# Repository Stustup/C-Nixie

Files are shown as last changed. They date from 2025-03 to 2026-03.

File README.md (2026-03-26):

<# CNIX - Nixie Tube Clock ->WORK IN PROGRESS

CNIX is a nixie tube clock which accepts many diffrent nixie tubes with only slight modifications to the tube carrier board. 

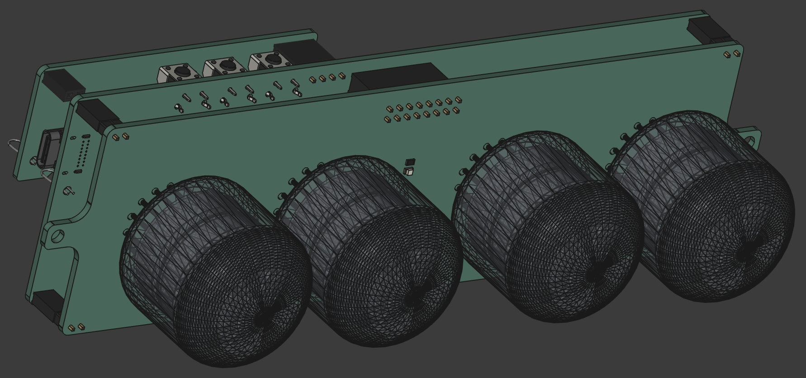
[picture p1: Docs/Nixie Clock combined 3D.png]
Nixie Clock tube board


The motivation was, that there are not many clocks out there that let you use almost any nixie tube you like. Most have fixed power supplies, 
underdesigned driver stages or inflexible microcontrollers. I hope to tackle these problems with an adjustable boost converter PSU, extremely 
flexible (and electrically protected) driver stages and an open source firmware written with free tools.

## Schematic

The control board consists of 3 parts:
- Power Supply
- Microcontroller
- I/O
- GPIO header for future ideas and feature expansion

Control board schematic

Power comes from a simple USB-C plug configured for 5V 3A max with the 5k1 CC line resistors. I thought about adding a PD controller for higher input voltages,
but this would just have added complexity and locked you into more expensive USB PD power supplies.

The µC is a STM32G051, because it has an included RTC *with* added Vbat pin for an external battery, so that the RTC remembers time even when powered off. 
The unused GPIOs are broken out to a connector, so that in the future one could add cool stuff like a radio time reciever, a display or wifi.
Time is set manually with the push buttons on top. 

The PSU is heavily inspired by [this site](https://surfncircuits.com/2018/02/03/optimizing-the-5v-to-170v-nixie-tube-power-supply-design-part-2/). I highly advise you giving it a read. The article goes in depth with boost converter design and its challanges.

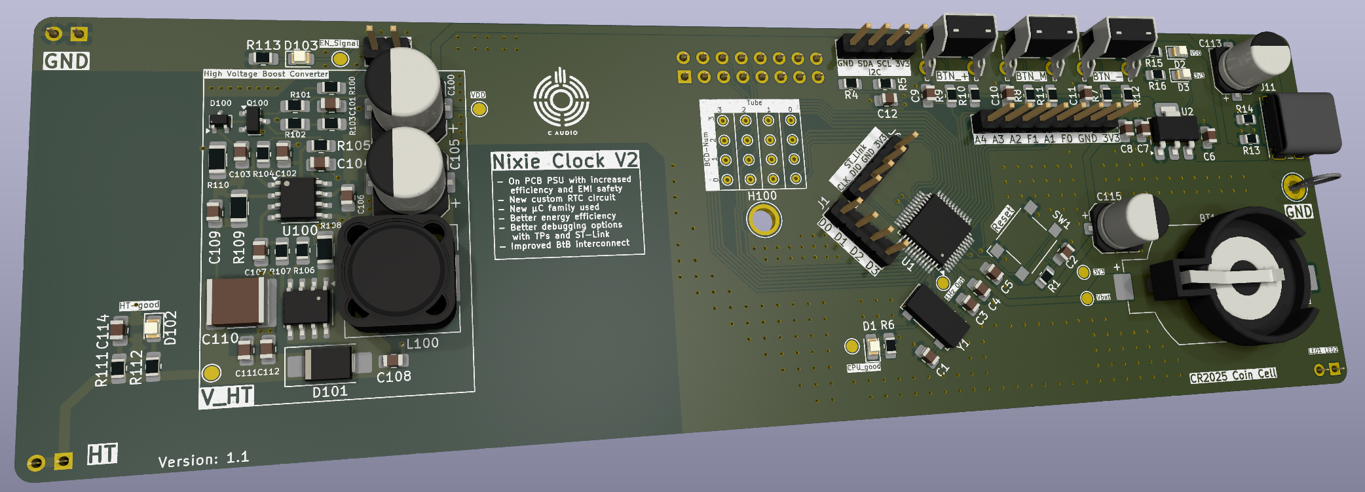
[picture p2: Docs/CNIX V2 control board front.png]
Control board 3d view


## Neat features

### Addon Boards
I designed an addon-board which just plugs into the broken out pins on the control board, to host all kinds of stuff. The one i already made has an DCF77 antenna for automatically getting the exact time OTA in germany. It also holds a HTU21 temperature and humidity sensor from TE, which can be accessed via a single press on the "menu" button on the control board. 
The addon-boards get detected via two pins (D2 a& D3), which form a 2 bit id system. so 0b11 means no board is connected, because i used internal pullups. the DCF77 board has the id 0b00, which deactivates the manual time setting menu and adds the temperature and humidity menu. 
With this all kinds of boards are possible, for example an ESP32 addon board with ESP-Home installed to integrate the clock and a sensor into homeassistant.

On the DCF77 Addon board there is a single pin to give structural strength to a simple perfboard on the main breakout bus. One can use this in tandem with the A1, A2, A3, A4, F0 and F1 pins.

![DCF77 Addon Board]

### Turn on/off timers
You can set power on and off times in the clock natively, so that the nixies dont always glow. With this the HT-power supply also gets deactivated to save power and lifespan of the parts. More advanced features like weekday dependant times have to be programmed directly into the µC, except if you want to code a big menu with just 3 buttons and 2 LEDs.

## TODO

- Change to new MCU. STM32H5 or ESP32. ESP32 for Wifi stuff like syncing time, Homeassistant integration etc. Could be done as module for the pinheader. STM32H5 for USBC pd
    - (DONE) Not necessary, BUT-> Create Plugin board for a DCF77 reciever conencting via GPIO
    - Addon board for Homeassistant Integration?
- (DONE) lower value caps for the LSE
- USB-PD (only with STM32H5) (Not neccessary)
- (DONE) HTU21 Temp and relative humidity sensor

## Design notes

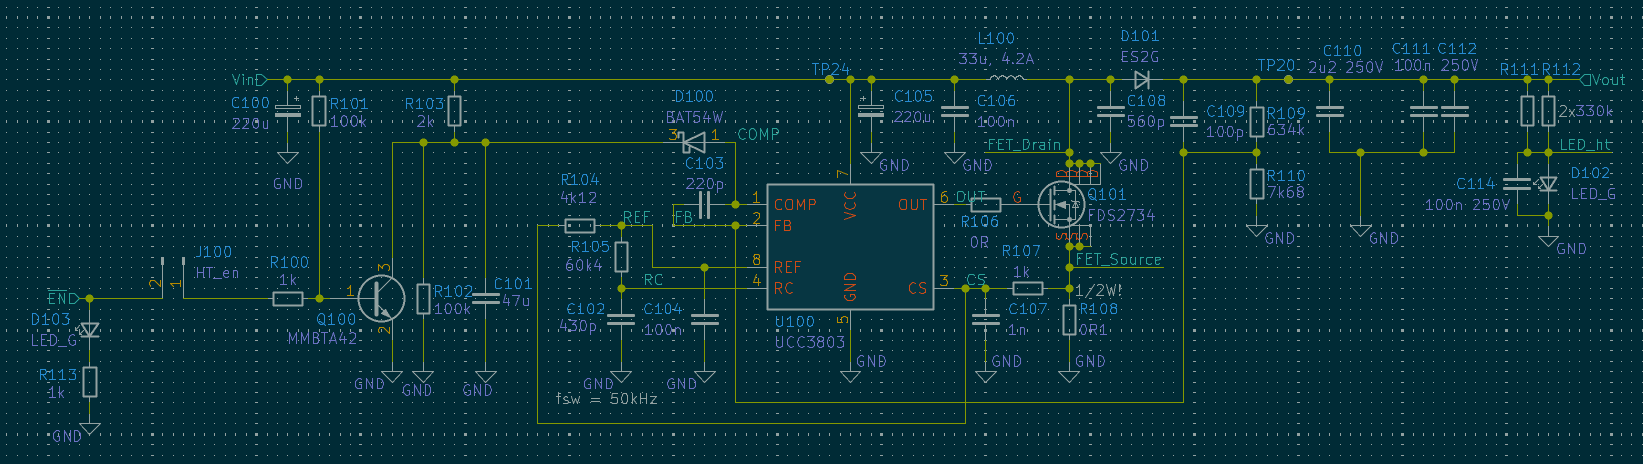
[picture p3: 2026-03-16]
Docs/CNIX V2 control board PSU schematic.png

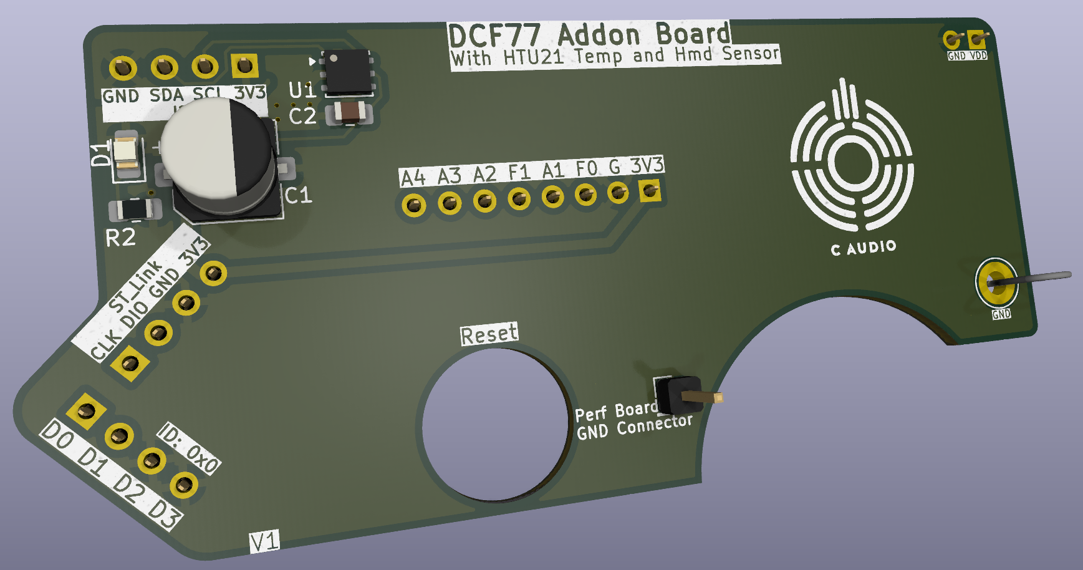
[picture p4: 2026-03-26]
Docs/CNIX V2 DCF77 Addon Board .png

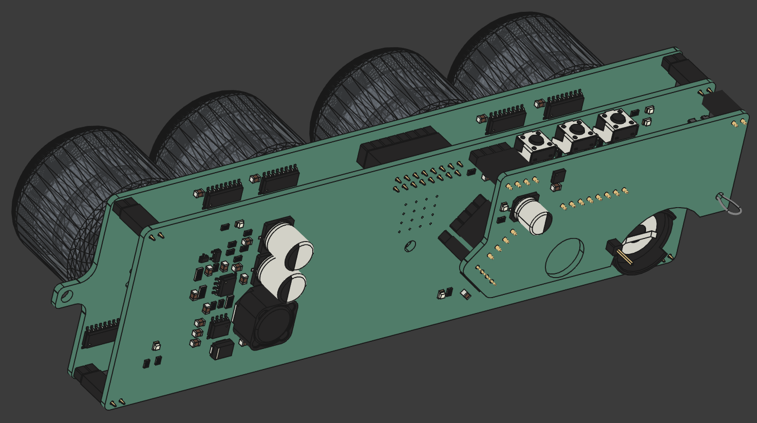
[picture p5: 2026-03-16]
Docs/CNIX V2 w Addon side.png

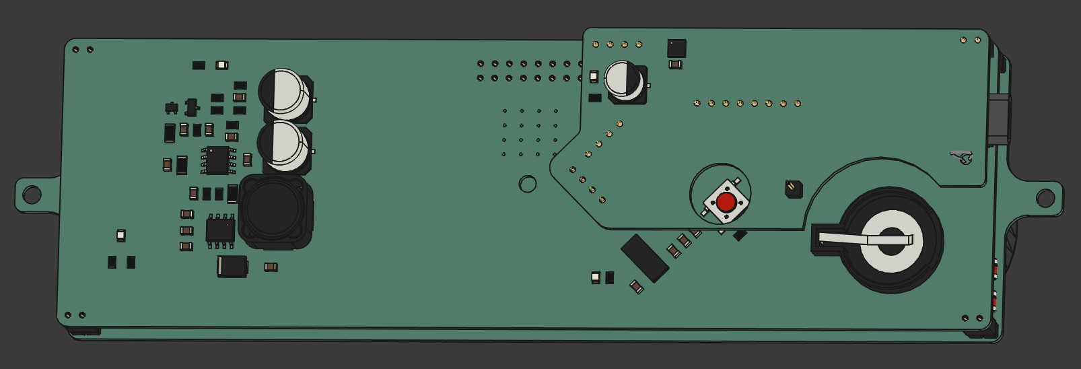
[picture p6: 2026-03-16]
Docs/CNIX V2 w addon back.png

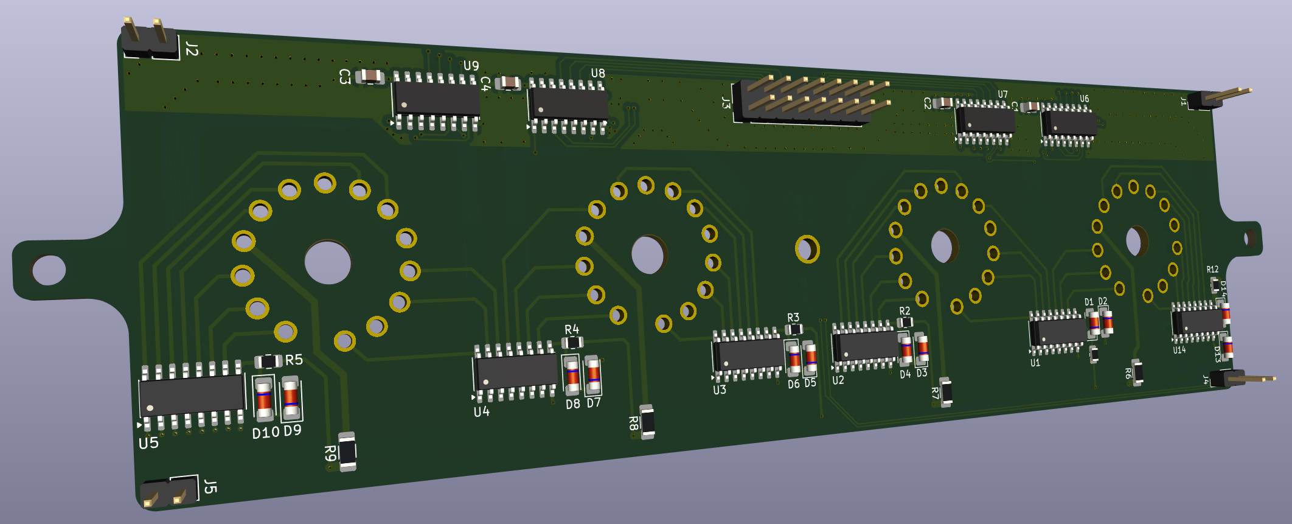
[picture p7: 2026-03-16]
Docs/CNIX V2 tube board side.png

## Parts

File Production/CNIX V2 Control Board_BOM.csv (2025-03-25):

Reference | Value | Qty | Mouser Nr. | Mouser URL | Datasheet | Footprint | DNP
BT1 | Coin Cell | 1 | 614-SMTU2032-LF.TR | https://www.mouser.de/ProductDetail/Renata/SMTU2032-LF.TR?qs=ZH26iPUykMX3HPCVulIAgQ%3D%3D | ~ | Battery:BatteryHolder_Renata_SMTU2032-LF_1x2032
C1,C3 | 18p | 2 | 80-C0805C180K5HACTU |  | ~ | Capacitor_SMD:C_0805_2012Metric_Pad1.18x1.45mm_HandSolder
C2,C4,C5,C8,C9,C10,C11,C104,C106 | 100n | 9 |  |  | ~ | Capacitor_SMD:C_0805_2012Metric_Pad1.18x1.45mm_HandSolder
C6,C12 | 10u | 2 | 187-CL21B106KPQNNNE |  | ~ | Capacitor_SMD:C_0805_2012Metric_Pad1.18x1.45mm_HandSolder
C7 | 22u | 1 | 187-CL21A226MQQNNNG |  | ~ | Capacitor_SMD:C_0805_2012Metric_Pad1.18x1.45mm_HandSolder
C100,C105 | 220u | 2 | 647-UUX1E221MNL6GS |  | ~ | Capacitor_SMD:CP_Elec_8x10
C101 | 47u | 1 | 187-CL21A476MRYNNNE |  | ~ | Capacitor_SMD:C_0805_2012Metric_Pad1.18x1.45mm_HandSolder
C102 | 430p | 1 | 80-C0805C431J5G |  | ~ | Capacitor_SMD:C_0805_2012Metric_Pad1.18x1.45mm_HandSolder
C103 | 220p | 1 | 710-885012207082 |  | ~ | Capacitor_SMD:C_0805_2012Metric_Pad1.18x1.45mm_HandSolder
C107 | 1n | 1 | 187-CL21B102KBANNNC |  | ~ | Capacitor_SMD:C_0805_2012Metric_Pad1.18x1.45mm_HandSolder
C108 | 560p | 1 | 80-C0805C561K2R |  | ~ | Capacitor_SMD:C_0805_2012Metric_Pad1.18x1.45mm_HandSolder
C109 | 100p | 1 | 581-08052C101K |  | ~ | Capacitor_SMD:C_0805_2012Metric_Pad1.18x1.45mm_HandSolder
C110,C111 | 1u 250V | 2 | 810-CGA4J3X7T2E104MA |  | ~ | Capacitor_SMD:C_0805_2012Metric_Pad1.18x1.45mm_HandSolder
C112 | 100n 250V | 1 | 810-CGA4J3X7T2E104MA |  | ~ | Capacitor_SMD:C_0805_2012Metric_Pad1.18x1.45mm_HandSolder
C113 | 100u 16V | 1 | 710-865080343009 | https://www.mouser.de/ProductDetail/Wurth-Elektronik/865080343009?qs=0KOYDY2FL28Gid9q%2FqirTQ%3D%3D | ~ | Capacitor_SMD:CP_Elec_6.3x7.7
D1,D2,D3 | LED_red | 3 |  |  | ~ | LED_SMD:LED_0805_2012Metric_Pad1.15x1.40mm_HandSolder
D100 | BAT54W | 1 | 637-BAT54W |  | https://assets.nexperia.com/documents/data-sheet/BAT54W_SER.pdf | Package_TO_SOT_SMD:SOT-323_SC-70
D101 | ES2G | 1 | 603-ES2G | https://eu.mouser.com/ProductDetail/YAGEO/ES2G?qs=2MMvu9PpTS2aUaVf2vcl5g%3D%3D | ~ | Diode_SMD:D_SMB_Handsoldering
D102,D103 | LED_G | 2 |  |  | ~ | LED_SMD:LED_0805_2012Metric
J1,J4 | EXT | 2 |  |  | ~ | Connector_PinHeader_2.54mm:PinHeader_1x04_P2.54mm_Vertical,Connector_PinHeader_2.54mm:PinHeader_1x08_P2.54mm_Vertical
J3 | Tube Out | 1 |  |  | ~ | Connector_PinSocket_2.54mm:PinSocket_2x08_P2.54mm_Vertical
J5 | I2C_ext | 1 |  |  | ~ | Connector_PinHeader_2.54mm:PinHeader_1x04_P2.54mm_Vertical
J6 | Prog | 1 |  |  | ~ | Connector_PinHeader_2.54mm:PinHeader_1x04_P2.54mm_Vertical
J7 | HT | 1 |  |  | ~ | Connector_PinSocket_2.54mm:PinSocket_1x02_P2.54mm_Vertical
J8,J9 | GND | 2 |  |  | ~ | Connector_PinSocket_2.54mm:PinSocket_1x02_P2.54mm_Vertical
J10 | LED | 1 |  |  | ~ | Connector_PinSocket_2.54mm:PinSocket_1x02_P2.54mm_Vertical
J11 | USB_C_Receptacle | 1 |  |  | https://www.usb.org/sites/default/files/documents/usb_type-c.zip | Connector_USB:USB_C_Receptacle_GCT_USB4085
L100 | 68u, 2.8A | 1 | 871-B82477R4683M100 | https://www.mouser.de/ProductDetail/EPCOS-TDK/B82477R4683M100?qs=oQHyZtUHWNVcdFSxmnJQSQ%3D%3D | ~ | Inductor_SMD:L_12x12mm_H8mm
Q100 | MMBTA42 | 1 |  |  | https://www.onsemi.com/pub/Collateral/MMBTA42LT1-D.PDF | Package_TO_SOT_SMD:SOT-23
Q101 | FDS2734 | 1 | 512-FDS2734 | https://eu.mouser.com/ProductDetail/onsemi-Fairchild/FDS2734?qs=OZ%252BC78tOsDbAOUY0TECDsw%3D%3D | https://ngspice.sourceforge.io/docs/ngspice-html-manual/manual.xhtml#cha_MOSFETs | Package_SO:SO-8_3.9x4.9mm_P1.27mm
R1 | 10k | 1 |  |  | ~ | Resistor_SMD:R_0805_2012Metric_Pad1.20x1.40mm_HandSolder
R4,R5,R6,R7,R8,R9,R10,R11,R12,R15 | 4k7 | 10 | 603-RC0805FR-074K7P |  | ~ | Resistor_SMD:R_0805_2012Metric_Pad1.20x1.40mm_HandSolder
R13,R14 | 5k1 | 2 | 652-CR0805FX-5101ELF |  | ~ | Resistor_SMD:R_0805_2012Metric_Pad1.20x1.40mm_HandSolder
R16,R103 | 2k | 2 | 603-RC0805FR-132KL |  | ~ | Resistor_SMD:R_0805_2012Metric_Pad1.20x1.40mm_HandSolder
R100,R107,R113 | 1k | 3 |  |  | ~ | Resistor_SMD:R_0805_2012Metric_Pad1.20x1.40mm_HandSolder
R101,R102 | 100k | 2 |  |  | ~ | Resistor_SMD:R_0805_2012Metric_Pad1.20x1.40mm_HandSolder
R104 | 4k12 | 1 | 603-RC0805FR-074K12L |  | ~ | Resistor_SMD:R_0805_2012Metric_Pad1.20x1.40mm_HandSolder
R105 | 47k | 1 | 603-RE0805FRE0747KL |  | ~ | Resistor_SMD:R_0805_2012Metric_Pad1.20x1.40mm_HandSolder
R106 | 0R | 1 |  |  | ~ | Resistor_SMD:R_0805_2012Metric_Pad1.20x1.40mm_HandSolder
R108 | 0R1 | 1 | 660-UR73VH2BTTDR100F | https://www.mouser.de/ProductDetail/KOA-Speer/UR73VH2BTTDR100F?qs=HoCaDK9Nz5dTWFlShnTmnw%3D%3D | https://www.koaspeer.com/pdfs/UR73V.pdf | Resistor_SMD:R_1206_3216Metric_Pad1.30x1.75mm_HandSolder
R109 | 634k | 1 | 71-CRCW0805634KFKEA |  | ~ | Resistor_SMD:R_1206_3216Metric_Pad1.30x1.75mm_HandSolder
R110 | 7k68 | 1 | 603-RC0805FR-077K68L |  | ~ | Resistor_SMD:R_1206_3216Metric_Pad1.30x1.75mm_HandSolder
R111,R112 | 330k | 2 | 603-AC0805FR-07330KL |  | ~ | Resistor_SMD:R_0805_2012Metric_Pad1.20x1.40mm_HandSolder
SW1 | RST | 1 |  |  | ~ | Button_Switch_SMD:SW_SPST_Omron_B3FS-100xP
SW2 | SW_Plus | 1 |  |  | ~ | Button_Switch_THT:SW_Tactile_SPST_Angled_PTS645Vx31-2LFS
SW3 | SW_Menu | 1 |  |  | ~ | Button_Switch_THT:SW_Tactile_SPST_Angled_PTS645Vx31-2LFS
SW4 | SW_Minus | 1 |  |  | ~ | Button_Switch_THT:SW_Tactile_SPST_Angled_PTS645Vx31-2LFS
TP1,TP2,TP3,TP4,TP5,TP6,TP7,TP8,TP9,TP10,TP11,TP12,TP13,TP14,TP15,TP16,TP17,TP18,TP19,TP20,TP22,TP23,TP24 | TestPoint_Small | 23 |  |  | ~ | TestPoint:TestPoint_Pad_D1.5mm,TestPoint:TestPoint_THTPad_D1.0mm_Drill0.5mm
U1 | STM32G051C8T3 | 1 | 511-STM32G051C8T3 | https://www.mouser.de/ProductDetail/STMicroelectronics/STM32G051C8T3?qs=T%252BzbugeAwjiuqacRoZ%252BJAg%3D%3D | https://www.mouser.de/datasheet/2/389/stm32g051c6-2449954.pdf | Package_QFP:LQFP-48_7x7mm_P0.5mm
U2 | AMS1117-3.3 | 1 |  |  | http://www.advanced-monolithic.com/pdf/ds1117.pdf | Package_TO_SOT_SMD:SOT-223-3_TabPin2
U100 | UCC3803 | 1 | 595-UCC3803DTR |  | http://www.ti.com/lit/ds/symlink/ucc3800.pdf | Package_SO:SOIC-8_3.9x4.9mm_P1.27mm
Y1 | ABS25-32.768KHZ | 1 | 815-ABS25-32.7-6-1-T | https://www.mouser.de/ProductDetail/ABRACON/ABS25-32.768KHZ-6-1-T?qs=3LVMET7lfiORXXovA%252BX5Lg%3D%3D | ~ | Crystal:Crystal_SMD_Abracon_ABS25-4Pin_8.0x3.8mm

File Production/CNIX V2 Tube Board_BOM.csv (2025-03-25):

Reference | Value | Qty | Mouser URL | Mouser Nr. | Datasheet | Footprint | DNP
C1,C2,C3,C4 | 100n | 4 |  |  | ~ | Capacitor_SMD:C_0805_2012Metric_Pad1.18x1.45mm_HandSolder
D1,D2,D3,D4,D5,D6,D7,D8,D9,D10,D13,D14 | TZMC47 | 12 | 78-TZMC47 |  | ~ | Diode_SMD:D_MiniMELF
D11,D12 | LED_Y | 2 |  |  | ~ | LED_SMD:LED_0805_2012Metric_Pad1.15x1.40mm_HandSolder
J1 | VDD | 1 |  |  | ~ | Connector_PinHeader_2.54mm:PinHeader_1x02_P2.54mm_Vertical
J2 | GND | 1 |  |  | ~ | Connector_PinHeader_2.54mm:PinHeader_1x02_P2.54mm_Vertical
J3 | Tube Conn | 1 |  |  | ~ | Connector_PinHeader_2.54mm:PinHeader_2x08_P2.54mm_Vertical
J4 | LED | 1 |  |  | ~ | Connector_PinHeader_2.54mm:PinHeader_1x02_P2.54mm_Vertical
J5 | HT | 1 |  |  | ~ | Connector_PinHeader_2.54mm:PinHeader_1x02_P2.54mm_Vertical
R1,R2,R3,R4,R5,R12 | 47k | 6 |  | 603-AC0805FR-1347KL | ~ | Resistor_SMD:R_0805_2012Metric
R6,R7,R8,R9 | 18k7 | 4 |  | 603-RC1206FR-0718K7L | ~ | Resistor_SMD:R_1206_3216Metric_Pad1.30x1.75mm_HandSolder
R10,R11 | 4k7 | 2 |  | 603-RC0805FR-074K7P | ~ | Resistor_SMD:R_0805_2012Metric_Pad1.20x1.40mm_HandSolder
U1,U2,U3,U4,U5,U14 | SN75468 | 6 | https://www.mouser.de/ProductDetail/Texas-Instruments/SN75468DR?qs=o4busQjUnQYJjs5DwORJyA%3D%3D | 595-SN75468DR | http://www.ti.com/lit/ds/slrs023e/slrs023e.pdf | Package_SO:SOIC-16_3.9x9.9mm_P1.27mm
U6,U7,U8,U9 | 4028 | 4 |  | 595-CD4028BM96 | http://www.intersil.com/content/dam/Intersil/documents/cd40/cd4028bms.pdf | Package_SO:SOIC-16_3.9x9.9mm_P1.27mm
U10 | IN-4_0 | 1 |  |  | https://www.tube-tester.com/sites/nixie/data/in-4/in-4-sh2.htm | .Nixie Tubes:IN-4
U11 | IN-4_1 | 1 |  |  | https://www.tube-tester.com/sites/nixie/data/in-4/in-4-sh2.htm | .Nixie Tubes:IN-4
U12 | IN-4_2 | 1 |  |  | https://www.tube-tester.com/sites/nixie/data/in-4/in-4-sh2.htm | .Nixie Tubes:IN-4
U13 | IN-4_3 | 1 |  |  | https://www.tube-tester.com/sites/nixie/data/in-4/in-4-sh2.htm | .Nixie Tubes:IN-4

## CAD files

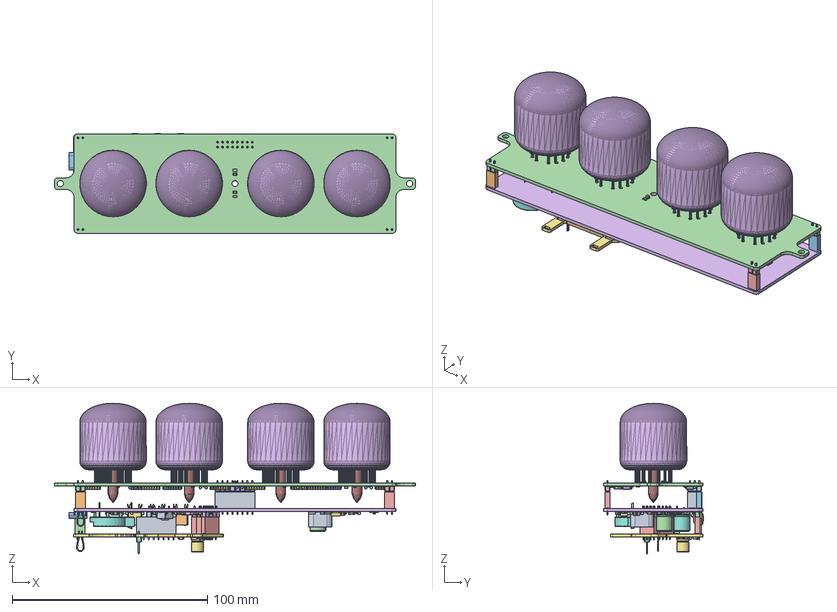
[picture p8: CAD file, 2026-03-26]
CAD/Nixie Clock 2 combined.FCStd
185.0 x 51.2 x 77.1 mm
R_1206_3216Metric
C_0805_2012Metric
C_0805_2012Metric002
C_0805_2012Metric004
C_0805_2012Metric006
R_0805_2012Metric
LED_0805_2012Metric
C_0805_2012Metric008
C_0805_2012Metric010
C_0805_2012Metric012
R_0805_2012Metric002
C_0805_2012Metric014
R_0805_2012Metric004
R_0805_2012Metric006
C_0805_2012Metric016
C_0805_2012Metric018
R_0805_2012Metric008
C_0805_2012Metric020
R_0805_2012Metric010
R_0805_2012Metric012
R_0805_2012Metric014
MicroCrystal_CC1V_T1A
R_0805_2012Metric016
R_1206_3216Metric002
C_0805_2012Metric022
R_0805_2012Metric018
R_0805_2012Metric020
C_0805_2012Metric024
R_0805_2012Metric022
TestPoint_Loop_D3.80mm_Drill2.0mm
SW_Tactile_SPST_Angled_PTS645Vx31-2LFS
SOT_23
PinHeader_1x06_P254mm_Vertical
C_0805_2012Metric026
R_0805_2012Metric024
C_0805_2012Metric028
C_0805_2012Metric030
R_0805_2012Metric026
C_0805_2012Metric032
SW_Tactile_SPST_Angled_PTS645Vx31-2LFS002
L_Coilcraft_MSS1278-XXX
R_0805_2012Metric028
SOT_323_SC_70
R_0805_2012Metric030
C_0805_2012Metric034
R_0805_2012Metric032
LED_0805_2012Metric002
CP_Elec_8x10
C_0805_2012Metric036
R_0805_2012Metric034
R_0805_2012Metric036
SOIC_8_39x49mm_P127mm
CQ assembly
CQ assembly001
CQ assembly002
CQ assembly003
CQ assembly004
CQ assembly005
CQ assembly006
CQ assembly007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

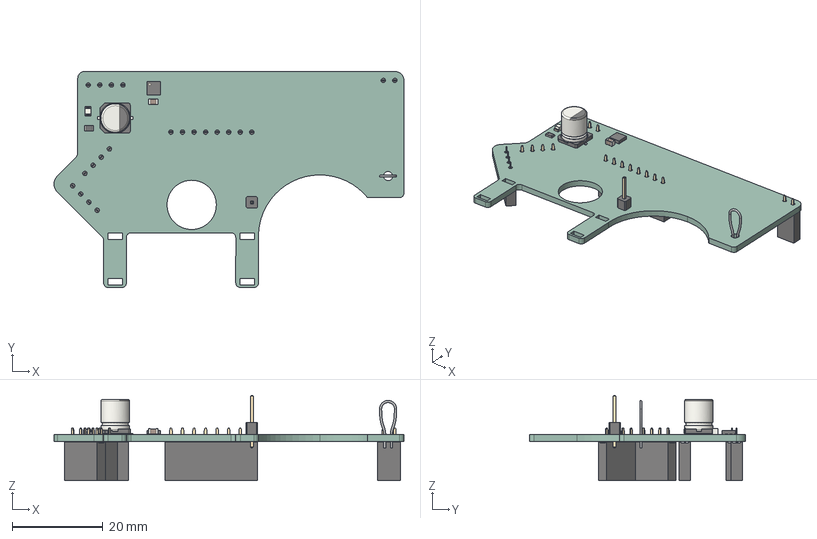
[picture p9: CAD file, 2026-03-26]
Hardware/Addon Boards/DCF77-Addon/3D/DCF77-Addon.step
77.0 x 47.5 x 18.7 mm
TestPoint_Loop_D3.80mm_Drill2.0mm
R_0805_2012Metric
CP_Elec_6.3x7.7
PinHeader_1x01_P2.54mm_Vertical
C_0805_2012Metric
LED_0805_2012Metric
DFN-6-1EP_3x3mm_P0.95mm_EP1.7x2.6mm
PinSocket_1x02_P2.54mm_Vertical
PinSocket_1x04_P2.54mm_Vertical x 3
PinSocket_1x08_P2.54mm_Vertical
DCF77-Addon_PCB

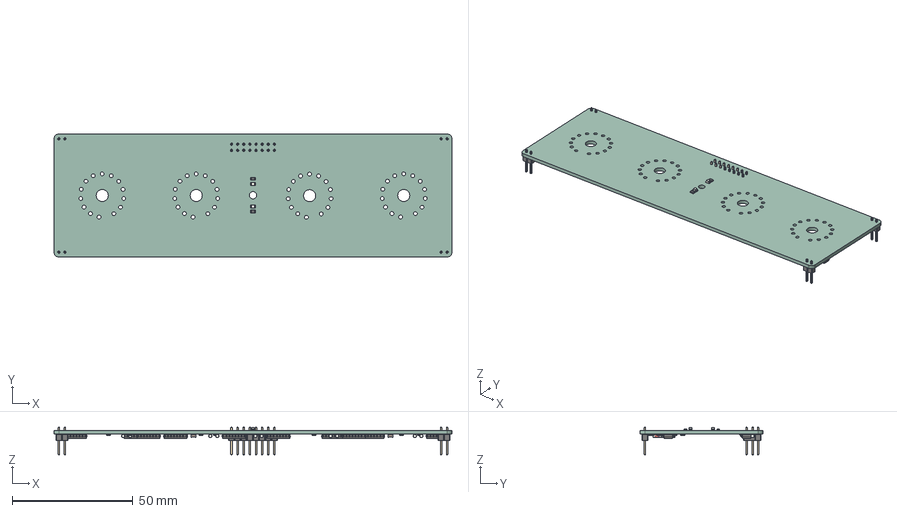
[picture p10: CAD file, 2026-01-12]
Hardware/Tube Board/CNIX V2 Tube Board IN13 (Placeholder)/CNIX V2 Tube Board.step
165.0 x 51.0 x 11.5 mm
R_0805_2012Metric x 8
LED_0805_2012Metric x 2
D_MiniMELF_Standard x 12
PinHeader_1x02_P254mm_Vertical x 4
SOIC_16_39x99mm_P127mm x 10
C_0805_2012Metric x 4
R_1206_3216Metric x 4
PinHeader_2x08_P254mm_Vertical
_autosave-Nixie Clock Tube Board V2_PCB

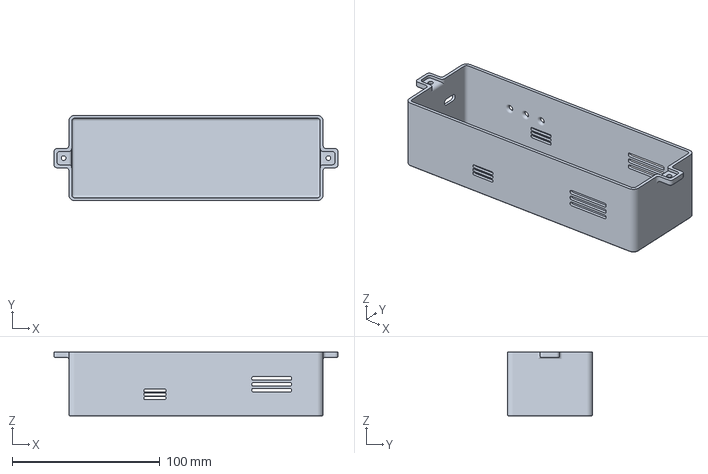
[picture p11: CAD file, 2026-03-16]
CAD/Nixie Clock 2 Case 3d-printing_3.3mf
192.0 x 57.8 x 43.2 mm

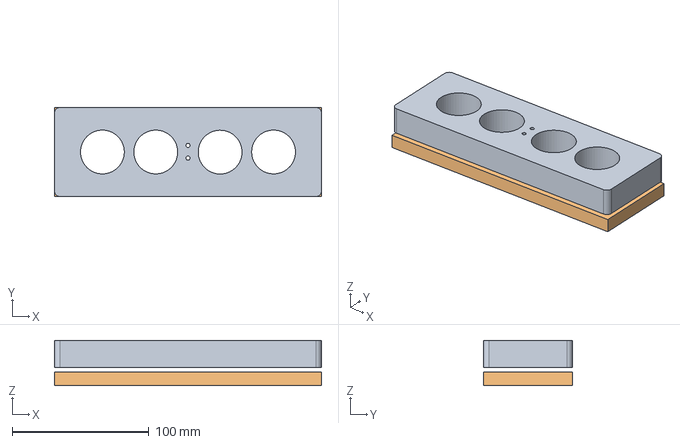
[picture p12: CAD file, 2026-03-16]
CAD/Nixie Clock 2 combined.sync-conflict-20260316-121056-62RYLVW.FCStd
195.0 x 65.0 x 33.2 mm
Frontplate
Fräs Vorlage Frontplatte

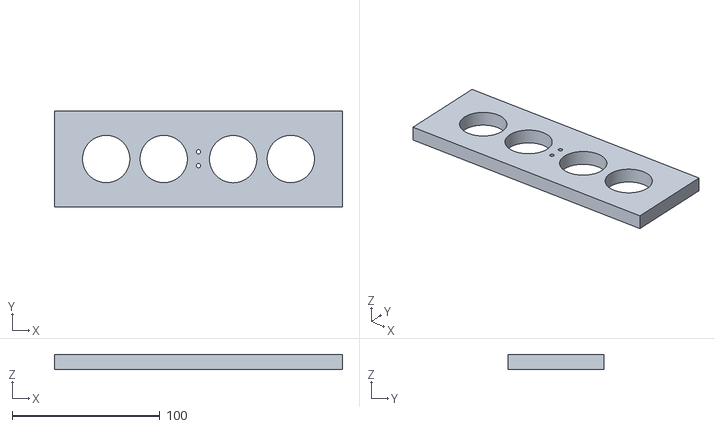
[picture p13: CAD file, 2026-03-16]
CAD/Nixie Clock 2 combined-Fräs Vorlage Frontplatte.stl
195.0 x 65.0 x 10.0

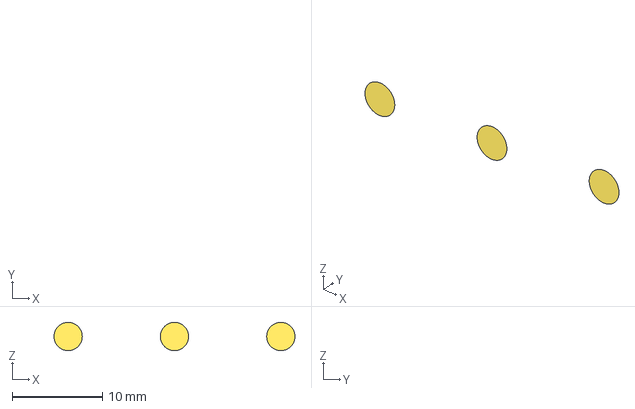
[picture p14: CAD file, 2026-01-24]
CAD/Nixie Clock 2 Case 3d-printing.step
26.7 x 0 x 3.14 mm

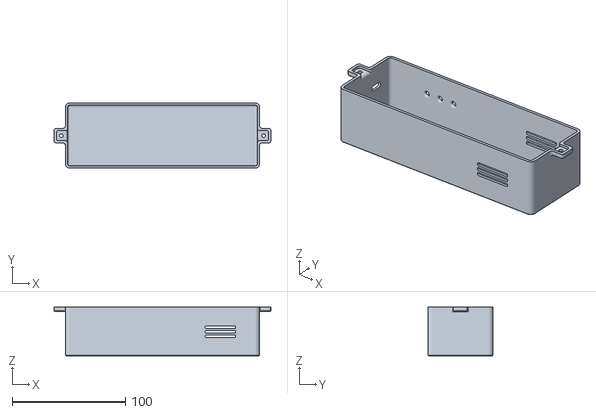
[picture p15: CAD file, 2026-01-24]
CAD/Nixie Clock 2 Case 3d-printing_2.stl
192.0 x 57.8 x 43.2

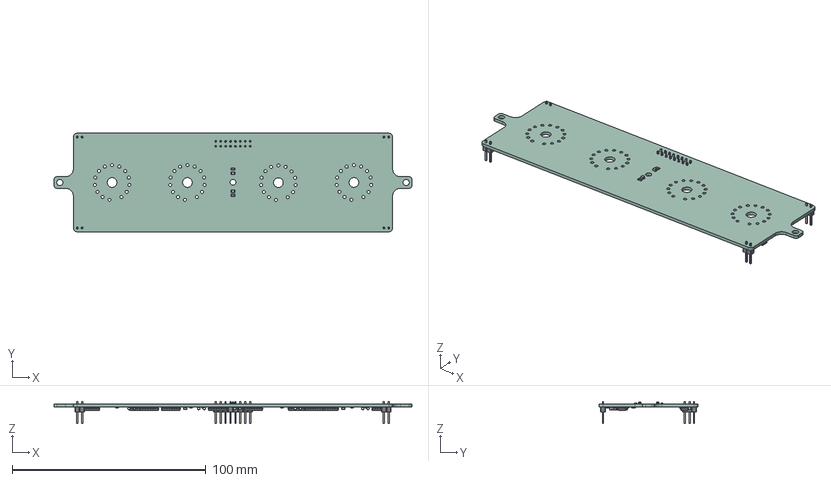
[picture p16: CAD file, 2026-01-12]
CAD/Nixie Clock Tube Board V2 IN4.step
185.0 x 51.0 x 11.5 mm
R_0805_2012Metric x 8
LED_0805_2012Metric x 2
D_MiniMELF x 12
PinHeader_1x02_P2.54mm_Vertical x 4
SOIC-16_3.9x9.9mm_P1.27mm x 10
C_0805_2012Metric x 4
R_1206_3216Metric x 4
PinHeader_2x08_P2.54mm_Vertical
CNIX V2 Tube Board_PCB

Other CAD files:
CAD/Case.FCStd
CAD/Nixie Clock 2 Case 3d-printing_3.stl
Hardware/Addon Boards/DCF77-Addon/3D/DCF77 Addon.FCStd

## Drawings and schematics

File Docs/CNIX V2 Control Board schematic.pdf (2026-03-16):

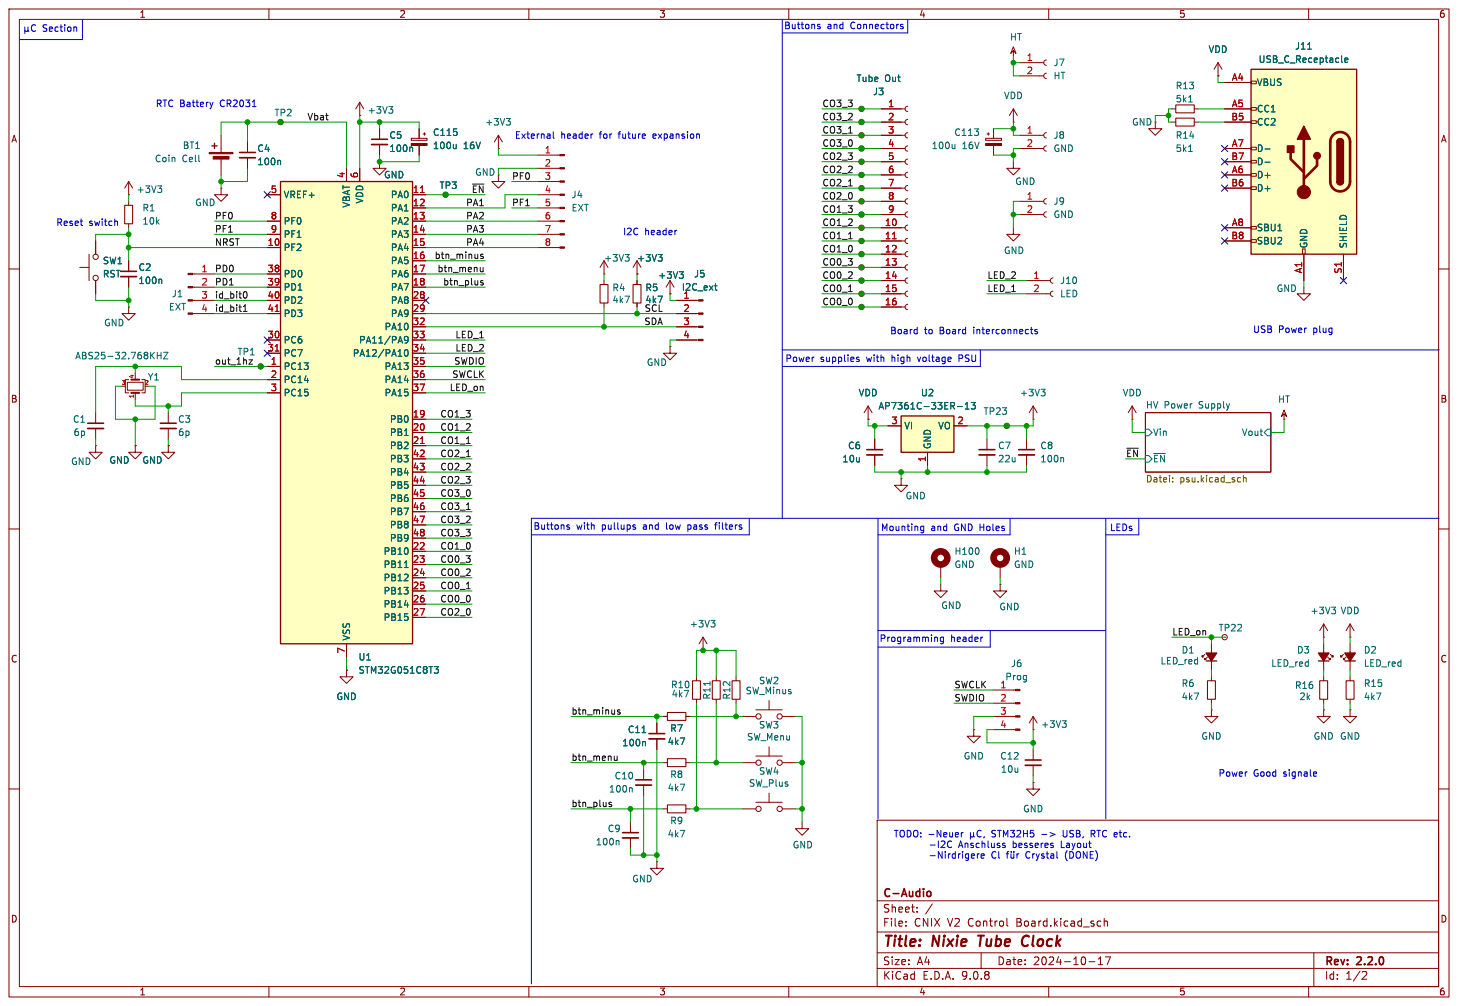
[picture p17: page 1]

Id: 1/2 Title: Nixie Tube Clock

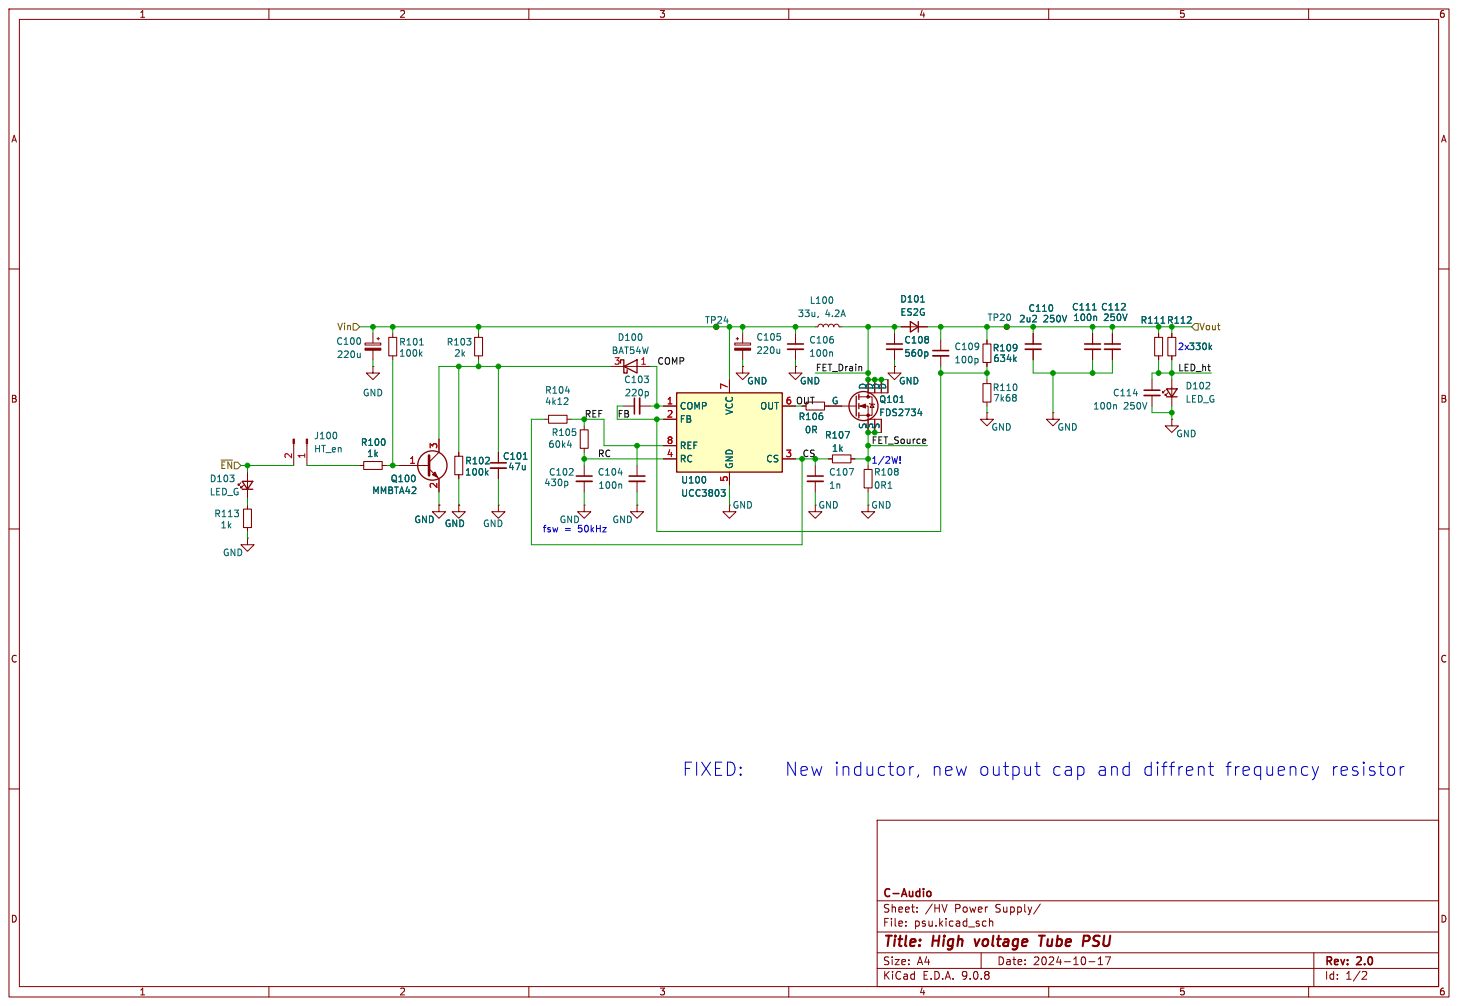
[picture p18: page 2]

Id: 1/2 Title: High voltage Tube PSU

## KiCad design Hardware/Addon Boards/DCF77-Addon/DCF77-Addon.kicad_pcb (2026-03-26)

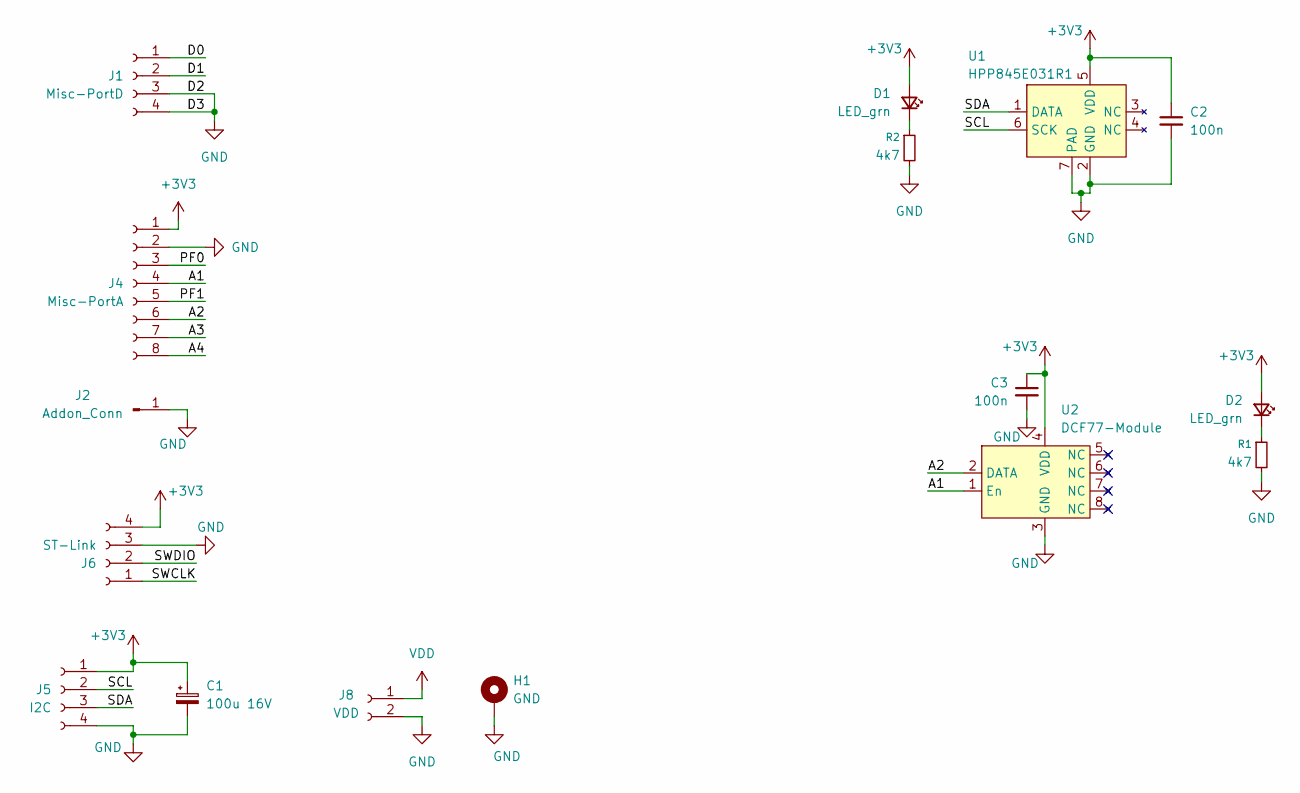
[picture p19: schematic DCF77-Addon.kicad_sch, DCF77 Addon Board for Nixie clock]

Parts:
C1: 100u 16V; CP_Elec_6.3x7.7
C2, C3: 100n; C_0805_2012Metric_Pad1.18x1.45mm_HandSolder
D1, D2: LED_grn; LED_0805_2012Metric_Pad1.15x1.40mm_HandSolder
H1: GND; TestPoint_Loop_D3.80mm_Drill2.0mm
J1: Misc-PortD; PinSocket_1x04_P2.54mm_Vertical
J2: Addon_Conn; PinHeader_1x01_P2.54mm_Vertical
J4: Misc-PortA; PinSocket_1x08_P2.54mm_Vertical
J5: I2C; PinSocket_1x04_P2.54mm_Vertical
J6: ST-Link; PinSocket_1x04_P2.54mm_Vertical
J8: VDD; PinSocket_1x02_P2.54mm_Vertical
R1, R2: 4k7; R_0805_2012Metric_Pad1.20x1.40mm_HandSolder
U1: HPP845E031R1; Maxim_TDFN-6-1EP_3x3mm_P0.95mm_EP1.5x2.3mm; Mouser Nr. 824-HPP845E031R1
U2: DCF77-Module

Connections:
+3V3: C1.1, C2.1, C3.1, D1.2 (A), D2.2 (A), J4.1, J5.1, J6.4, U1.5 (VDD), U2.4 (VDD)
/A1: J4.4, U2.1 (En)
/A2: J4.6, U2.2 (DATA)
/A3: J4.7
/A4: J4.8
/D0: J1.1
/D1: J1.2
/PF0: J4.3
/PF1: J4.5
/SCL: J5.2, U1.6 (SCK)
/SDA: J5.3, U1.1 (DATA)
/SWCLK: J6.1
/SWDIO: J6.2
GND: C1.2, C2.2, C3.2, H1.1, J1.3, J1.4, J2.1, J4.2, J5.4, J6.3, J8.2, R1.2, R2.2, U1.2 (GND), U1.7 (PAD), U2.3 (GND)
unnamed: D1.1 (K), R2.1
unnamed: D2.1 (K), R1.1
VDD: J8.1

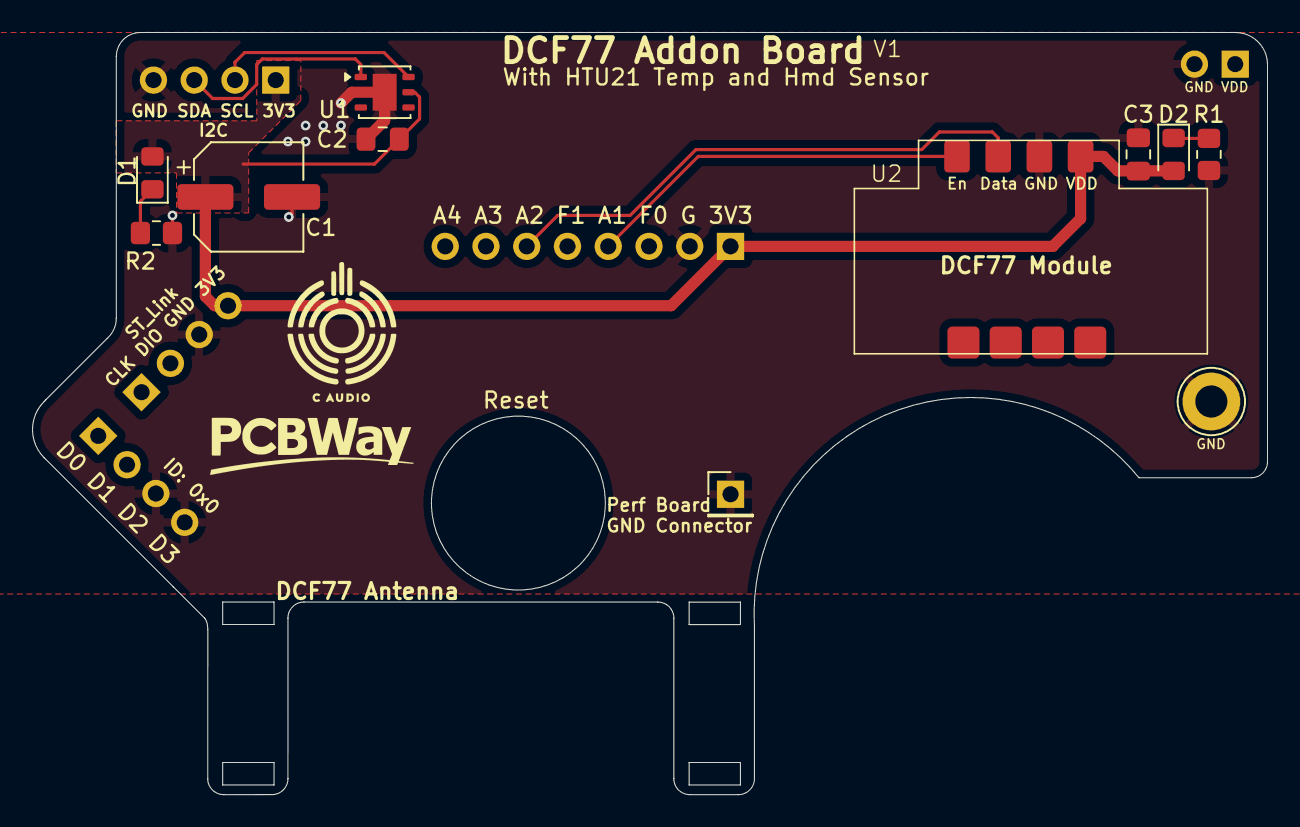
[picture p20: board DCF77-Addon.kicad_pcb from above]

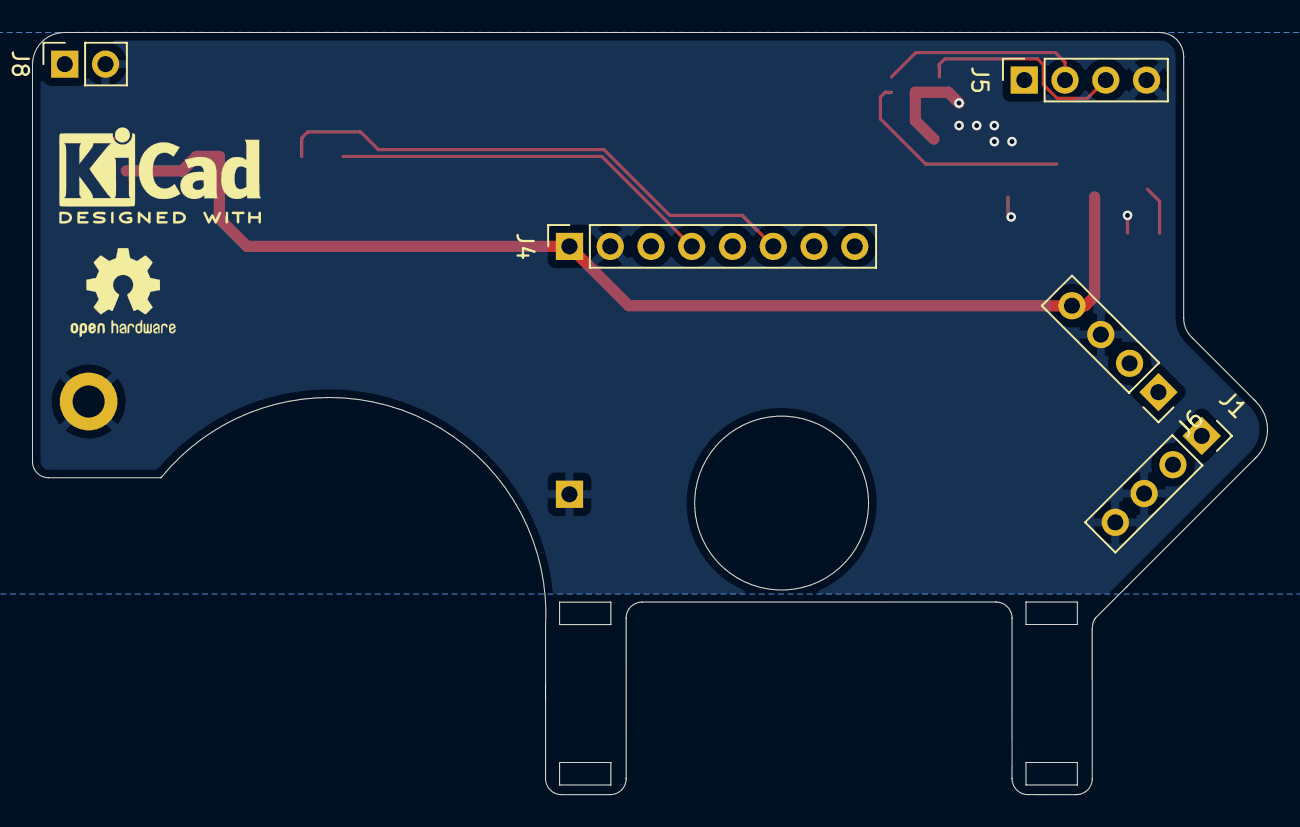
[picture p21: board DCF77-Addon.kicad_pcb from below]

Board: 2 copper layers, 77.0 x 47.5 mm, 16 parts (5 on the bottom side), 8 nets.

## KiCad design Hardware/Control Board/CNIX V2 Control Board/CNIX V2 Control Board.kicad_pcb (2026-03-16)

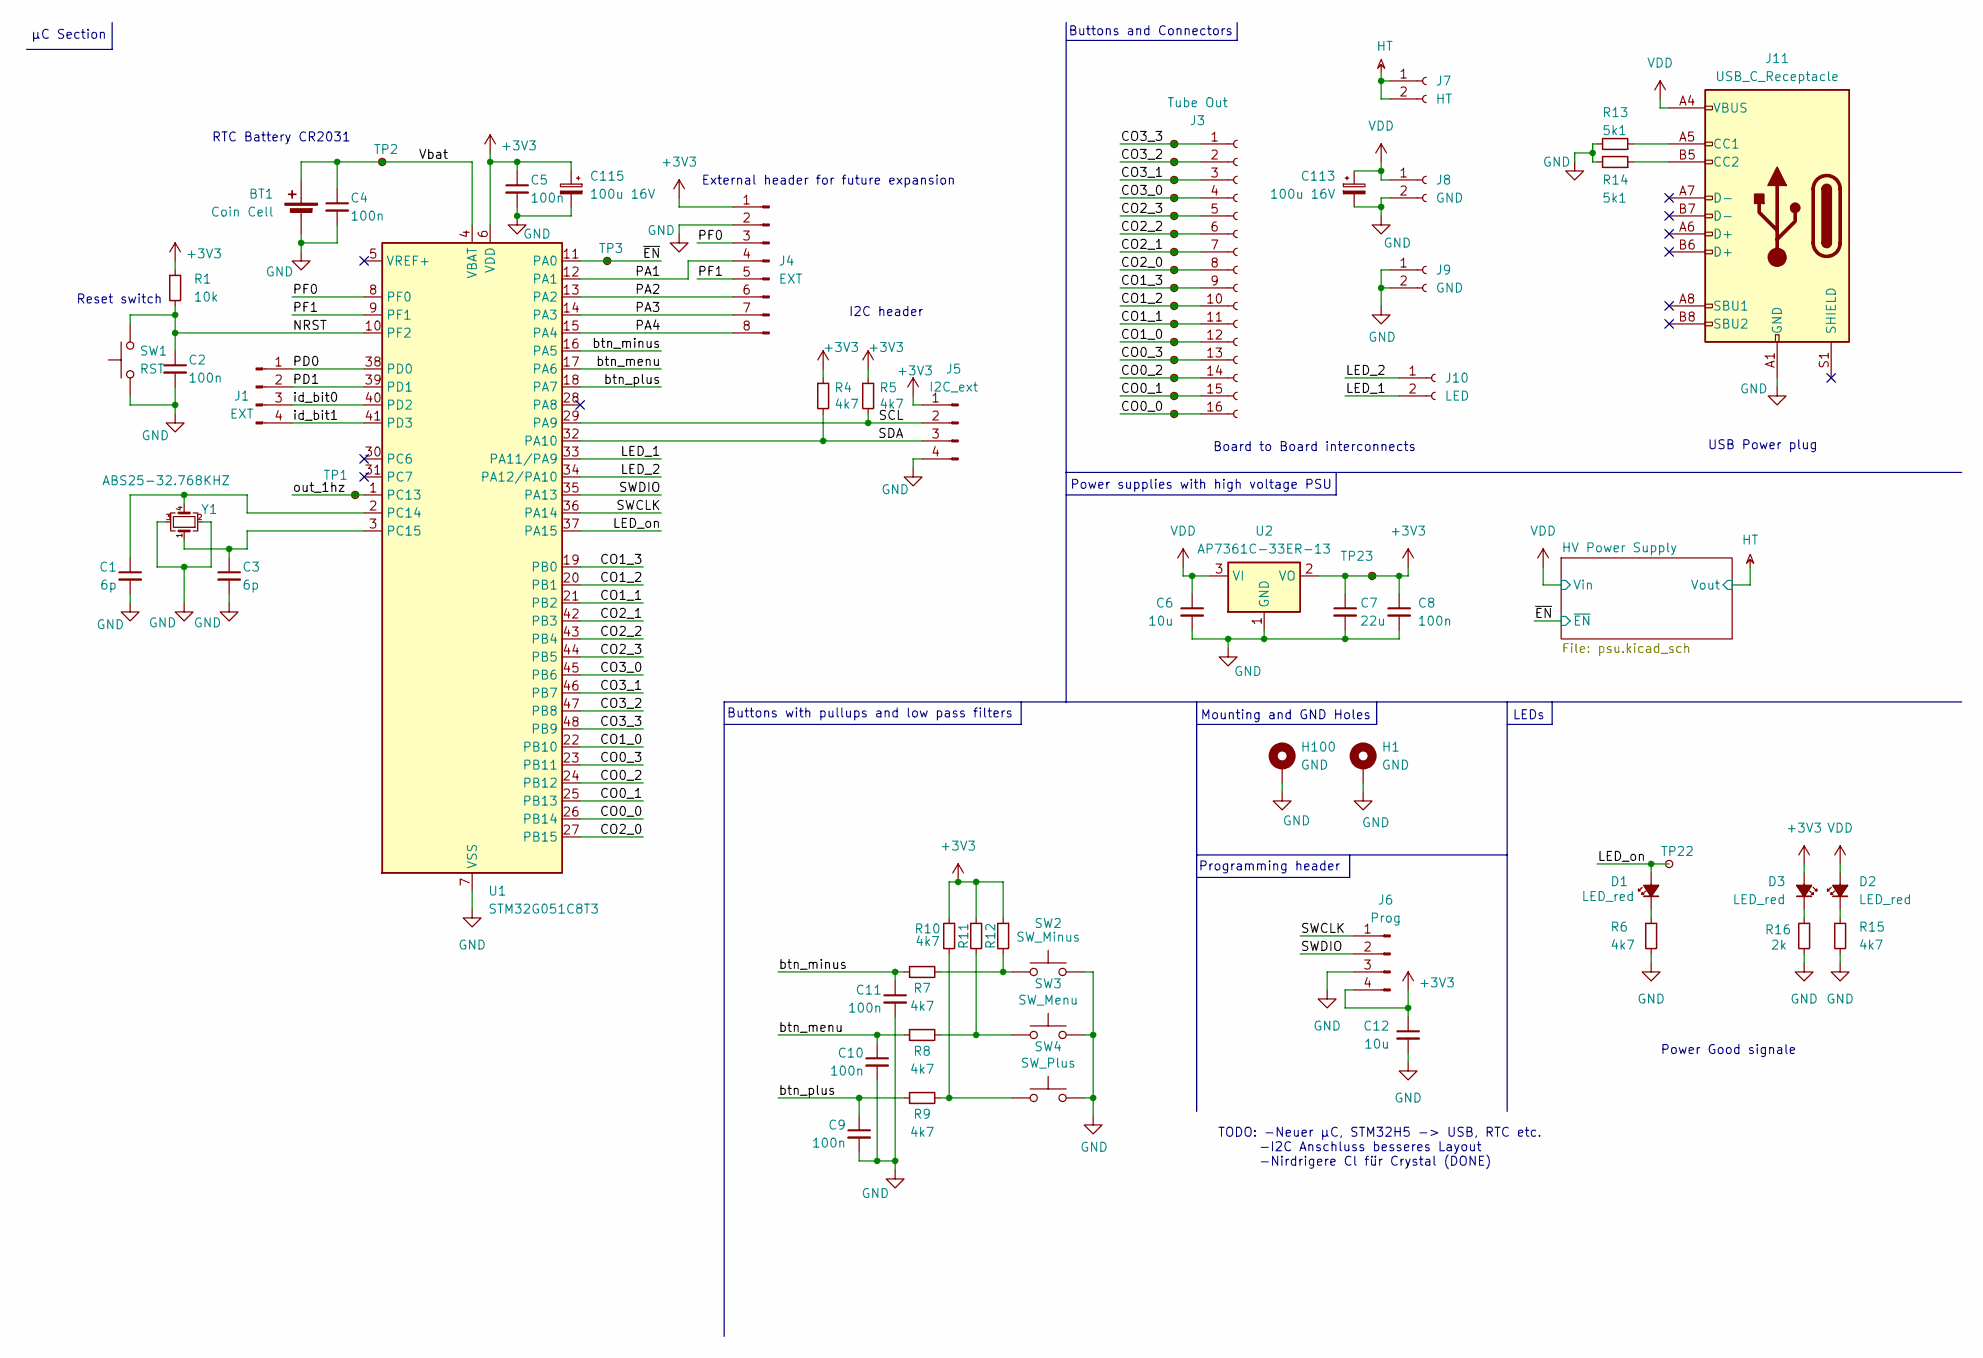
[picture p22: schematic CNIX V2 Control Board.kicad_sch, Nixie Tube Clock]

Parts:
BT1: Coin Cell; BatteryHolder_Renata_SMTU2032-LF_1x2032; Mouser Nr. 614-SMTU2032-LF.TR
C1, C3: 6p; C_0805_2012Metric_Pad1.18x1.45mm_HandSolder; Mouser Nr. 80-C0805C180K5HACTU
C2, C4, C5, C8, C9, C10, C11: 100n; C_0805_2012Metric_Pad1.18x1.45mm_HandSolder
C6, C12: 10u; C_0805_2012Metric_Pad1.18x1.45mm_HandSolder; Mouser Nr. 187-CL21B106KPQNNNE
C7: 22u; C_0805_2012Metric_Pad1.18x1.45mm_HandSolder; Mouser Nr. 187-CL21A226MQQNNNG
C113, C115: 100u 16V; CP_Elec_6.3x7.7; Mouser Nr. 710-865080343009
D1, D2, D3: LED_red; LED_0805_2012Metric_Pad1.15x1.40mm_HandSolder
H1: GND; TestPoint_Loop_D3.80mm_Drill2.0mm
H100: GND; TestPoint_Plated_Hole_D3.0mm
J1: EXT; PinHeader_1x04_P2.54mm_Vertical
J3: Tube Out; PinSocket_2x08_P2.54mm_Vertical
J4: EXT; PinHeader_1x08_P2.54mm_Vertical
J5: I2C_ext; PinHeader_1x04_P2.54mm_Vertical
J6: Prog; PinHeader_1x04_P2.54mm_Vertical
J7: HT; PinSocket_1x02_P2.54mm_Vertical
J8, J9: GND; PinSocket_1x02_P2.54mm_Vertical
J10: LED; PinSocket_1x02_P2.54mm_Vertical
J11: USB_C_Receptacle; USB_C_Receptacle_GCT_USB4085
R1: 10k; R_0805_2012Metric_Pad1.20x1.40mm_HandSolder
R4, R5, R6, R7, R8, R9, R10, R11, R12, R15: 4k7; R_0805_2012Metric_Pad1.20x1.40mm_HandSolder; Mouser Nr. 603-RC0805FR-074K7P
R13, R14: 5k1; R_0805_2012Metric_Pad1.20x1.40mm_HandSolder; Mouser Nr. 652-CR0805FX-5101ELF
R16: 2k; R_0805_2012Metric_Pad1.20x1.40mm_HandSolder; Mouser Nr. 603-RC0805FR-132KL
SW1: RST; SW_SPST_Omron_B3FS-100xP
SW2: SW_Minus; SW_Tactile_SPST_Angled_PTS645Vx31-2LFS
SW3: SW_Menu; SW_Tactile_SPST_Angled_PTS645Vx31-2LFS
SW4: SW_Plus; SW_Tactile_SPST_Angled_PTS645Vx31-2LFS
TP1, TP2, TP3, TP22, TP23: TestPoint_Small; TestPoint_Pad_D1.5mm
TP4, TP5, TP6, TP7, TP8, TP9, TP10, TP11, TP12, TP13, TP14, TP15, TP16, TP17, TP18, TP19: TestPoint_Small; TestPoint_THTPad_D1.0mm_Drill0.5mm
U1: STM32G051C8T3; LQFP-48_7x7mm_P0.5mm; Mouser Nr. 511-STM32G051C8T3
U2: AP7361C-33ER-13; SOT-223-3_TabPin2; Mouser-Nr. 621-AP7361C-33ER-13
Y1: ABS25-32.768KHZ; Crystal_SMD_Abracon_ABS25-4Pin_8.0x3.8mm; Mouser Nr. 815-ABS25-32.7-6-1-T

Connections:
+3V3: C5.1, C7.1, C8.1, C12.1, C115.1, D3.2 (A), J4.1, J5.1, J6.4, R1.1, R4.1, R5.1, R10.2, R11.1, R12.1, TP23.1, U1.6 (VDD), U2.2 (VO)
/CO0_0: J3.16, TP19.1, U1.26 (PB14)
/CO0_1: J3.15, TP18.1, U1.25 (PB13)
/CO0_2: J3.14, TP17.1, U1.24 (PB12)
/CO0_3: J3.13, TP16.1, U1.23 (PB11)
/CO1_0: J3.12, TP15.1, U1.22 (PB10)
/CO1_1: J3.11, TP14.1, U1.21 (PB2)
/CO1_2: J3.10, TP13.1, U1.20 (PB1)
/CO1_3: J3.9, TP12.1, U1.19 (PB0)
/CO2_0: J3.8, TP11.1, U1.27 (PB15)
/CO2_1: J3.7, TP10.1, U1.42 (PB3)
/CO2_2: J3.6, TP9.1, U1.43 (PB4)
/CO2_3: J3.5, TP8.1, U1.44 (PB5)
/CO3_0: J3.4, TP7.1, U1.45 (PB6)
/CO3_1: J3.3, TP6.1, U1.46 (PB7)
/CO3_2: J3.2, TP5.1, U1.47 (PB8)
/CO3_3: J3.1, TP4.1, U1.48 (PB9)
/LED_1: J10.2, U1.33 (PA11/PA9)
/LED_2: J10.1, U1.34 (PA12/PA10)
/LED_on: D1.2 (A), TP22.1, U1.37 (PA15)
/NRST: C2.1, R1.2, SW1.2, U1.10 (PF2)
/PA1: J4.4, U1.12 (PA1)
/PA2: J4.6, U1.13 (PA2)
/PA3: J4.7, U1.14 (PA3)
/PA4: J4.8, U1.15 (PA4)
/PD0: J1.1, U1.38 (PD0)
/PD1: J1.2, U1.39 (PD1)
/PF0: J4.3, U1.8 (PF0)
/PF1: J4.5, U1.9 (PF1)
/SCL: J5.2, R5.2, U1.29 (PA9)
/SDA: J5.3, R4.2, U1.32 (PA10)
/SWCLK: J6.1, U1.36 (PA14)
/SWDIO: J6.2, U1.35 (PA13)
/Vbat: BT1.1 (+), C4.1, TP2.1, U1.4 (VBAT)
/btn_menu: C10.1, R8.1, U1.17 (PA6)
/btn_minus: C11.1, R7.1, U1.16 (PA5)
/btn_plus: C9.1, R9.1, U1.18 (PA7)
/id_bit0: J1.3, U1.40 (PD2)
/id_bit1: J1.4, U1.41 (PD3)
/out_1hz: TP1.1, U1.1 (PC13)
/~EN: TP3.1, U1.11 (PA0); also elsewhere on the board
GND: BT1.2 (-), C1.2, C2.2, C3.2, C4.2, C5.2, C6.2, C7.2, C8.2, C9.2, C10.2, C11.2, C12.2, C113.2, C115.2, H1.1, H100.1, J4.2, J5.4, J6.3, J8.2, J9.1, J9.2, J11.A1 (GND), J11.A12 (GND), J11.B1 (GND), J11.B12 (GND), R6.2, R13.2, R14.2, R15.2, R16.2, SW1.1, SW2.2, SW3.2, SW4.2, U1.7 (VSS), U2.1 (GND), Y1.2, Y1.3; also elsewhere on the board
HT: J7.1, J7.2; also elsewhere on the board
unnamed: D1.1 (K), R6.1
unnamed: D2.1 (K), R15.1
unnamed: D3.1 (K), R16.1
unnamed: J11.A5 (CC1), R13.1
unnamed: J11.B5 (CC2), R14.1
unnamed: R9.2, R10.1, SW4.1
unnamed: R8.2, R11.2, SW3.1
unnamed: R7.2, R12.2, SW2.1
unnamed: C1.1, U1.2 (PC14), Y1.4
unnamed: C3.1, U1.3 (PC15), Y1.1
VDD: C6.1, C113.1, D2.2 (A), J8.1, J11.A4 (VBUS), J11.A9 (VBUS), J11.B4 (VBUS), J11.B9 (VBUS), U2.3 (VI); also elsewhere on the board

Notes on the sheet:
Board to Board interconnects
RTC Battery CR2031
µC Section
Programming header
External header for future expansion
Mounting and GND Holes
TODO: -Neuer µC, STM32H5 -> USB, RTC etc. -I2C Anschluss besseres Layout -Nirdrigere Cl für Crystal (DONE)
Power supplies with high voltage PSU
Buttons with pullups and low pass filters
Power Good signale
I2C header
USB Power plug
Reset switch
LEDs
Buttons and Connectors

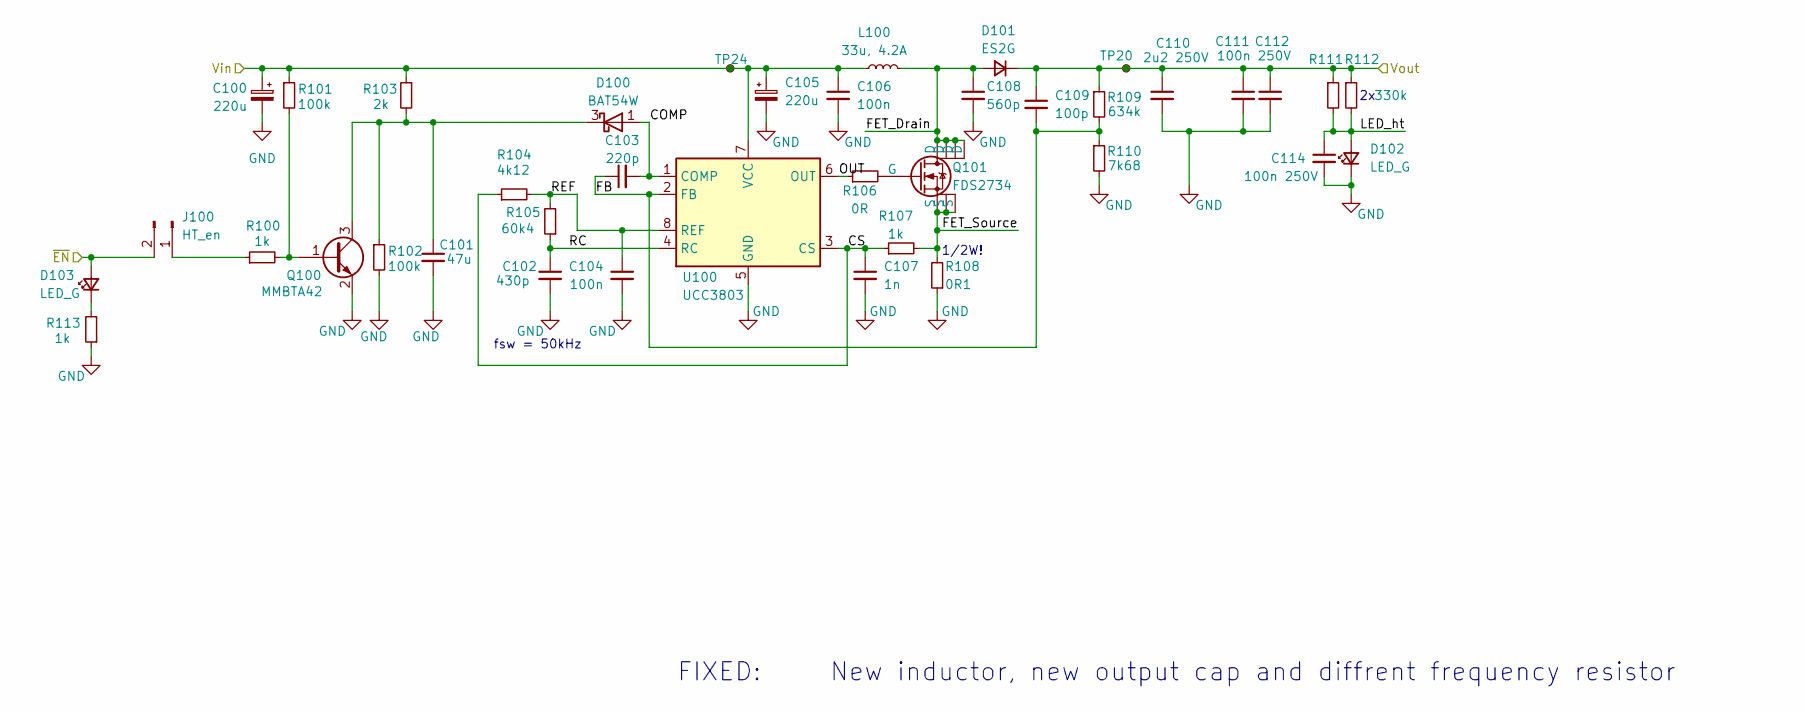
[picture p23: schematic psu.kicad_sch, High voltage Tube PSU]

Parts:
C100, C105: 220u; CP_Elec_8x10; Mouser Nr. 647-UUX1E221MNL6GS
C101: 47u; C_0805_2012Metric_Pad1.18x1.45mm_HandSolder; Mouser Nr. 187-CL21A476MRYNNNE
C102: 430p; C_0805_2012Metric_Pad1.18x1.45mm_HandSolder; Mouser Nr. 80-C0805C431J5G
C103: 220p; C_0805_2012Metric_Pad1.18x1.45mm_HandSolder; Mouser Nr. 710-885012207082
C104, C106: 100n; C_0805_2012Metric_Pad1.18x1.45mm_HandSolder
C107: 1n; C_0805_2012Metric_Pad1.18x1.45mm_HandSolder; Mouser Nr. 187-CL21B102KBANNNC
C108: 560p; C_0805_2012Metric_Pad1.18x1.45mm_HandSolder; Mouser Nr. 80-C0805C561K2R
C109: 100p; C_0805_2012Metric_Pad1.18x1.45mm_HandSolder; Mouser Nr. 581-08052C101K
C110: 2u2 250V; C_2220_5750Metric_Pad1.97x5.40mm_HandSolder; Mouser Nr. 710-885342214003
C111: 100nf 250V; C_0805_2012Metric_Pad1.18x1.45mm_HandSolder; Mouser Nr. 810-CGA4J3X7T2E104MA
C112, C114: 100n 250V; C_0805_2012Metric_Pad1.18x1.45mm_HandSolder; Mouser Nr. 810-CGA4J3X7T2E104MA
D100: BAT54W; SOT-323_SC-70; Mouser-Nr. 637-BAT54W
D101: ES2G; D_SMB_Handsoldering; Mouser Nr. 603-ES2G
D102, D103: LED_G; LED_0805_2012Metric
J100: HT_en; PinHeader_1x02_P2.54mm_Vertical
L100: 33u, 4.2A; L_12x12mm_H8mm; Mouser Nr. 7447709330
Q100: MMBTA42; SOT-23
Q101: FDS2734; SO-8_3.9x4.9mm_P1.27mm; Mouser Nr. 512-FDS2734
R100, R107, R113: 1k; R_0805_2012Metric_Pad1.20x1.40mm_HandSolder
R101, R102: 100k; R_0805_2012Metric_Pad1.20x1.40mm_HandSolder
R103: 2k; R_0805_2012Metric_Pad1.20x1.40mm_HandSolder; Mouser Nr. 603-RC0805FR-132KL
R104: 4k12; R_0805_2012Metric_Pad1.20x1.40mm_HandSolder; Mouser Nr. 603-RC0805FR-074K12L
R105: 60k4; R_0805_2012Metric_Pad1.20x1.40mm_HandSolder; Mouser Nr. 603-RE0805FRE0747KL
R106: 0R; R_0805_2012Metric_Pad1.20x1.40mm_HandSolder
R108: 0R1; R_1206_3216Metric_Pad1.30x1.75mm_HandSolder; Mouser Nr. 660-UR73VH2BTTDR100F
R109: 634k; R_1206_3216Metric_Pad1.30x1.75mm_HandSolder; Mouser Nr. 71-CRCW0805634KFKEA
R110: 7k68; R_1206_3216Metric_Pad1.30x1.75mm_HandSolder; Mouser Nr. 603-RC0805FR-077K68L
R111, R112: 330k; R_0805_2012Metric_Pad1.20x1.40mm_HandSolder; Mouser Nr. 603-AC0805FR-07330KL
TP20, TP24: TestPoint_Small; TestPoint_Pad_D1.5mm
U100: UCC3803; SOIC-8_3.9x4.9mm_P1.27mm; Mouser Nr. 595-UCC3803DTR

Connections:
/HV Power Supply/COMP: C103.2, D100.1 (A), U100.1 (COMP)
/HV Power Supply/CS: C107.1, R104.1, R107.1, U100.3 (CS)
/HV Power Supply/FB: C103.1, C109.2, R109.2, R110.1, U100.2 (FB)
/HV Power Supply/FET_Drain: C108.1, D101.2 (A), L100.2, Q101.5 (D), Q101.6 (D), Q101.7 (D), Q101.8 (D)
/HV Power Supply/FET_Source: Q101.1 (S), Q101.2 (S), Q101.3 (S), R107.2, R108.2
/HV Power Supply/LED_ht: C114.1, D102.2 (A), R111.2, R112.2
/HV Power Supply/OUT: R106.1, U100.6 (OUT)
/HV Power Supply/RC: C102.1, R105.1, U100.4 (RC)
/HV Power Supply/REF: C104.1, R104.2, R105.2, U100.8 (REF)
/~EN: D103.2 (A), J100.2; also elsewhere on the board
GND: C100.2, C101.2, C102.2, C104.2, C105.2, C106.2, C107.2, C108.2, C110.2, C111.2, C112.2, C114.2, D102.1 (K), Q100.2 (E), R102.2, R108.1, R110.2, R113.1, U100.5 (GND); also elsewhere on the board
HT: C109.1, C110.1, C111.1, C112.1, D101.1 (K), R109.1, R111.1, R112.1, TP20.1; also elsewhere on the board
unnamed: C101.1, D100.3 (K), Q100.3 (C), R102.1, R103.2
unnamed: D103.1 (K), R113.2
unnamed: J100.1, R100.1
unnamed: Q100.1 (B), R100.2, R101.2
unnamed: Q101.4 (G), R106.2
VDD: C100.1, C105.1, C106.1, L100.1, R101.1, R103.1, TP24.1, U100.7 (VCC); also elsewhere on the board

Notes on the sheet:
FIXED: New inductor, new output cap and diffrent frequency resistor
fsw = 50kHz
1/2W!

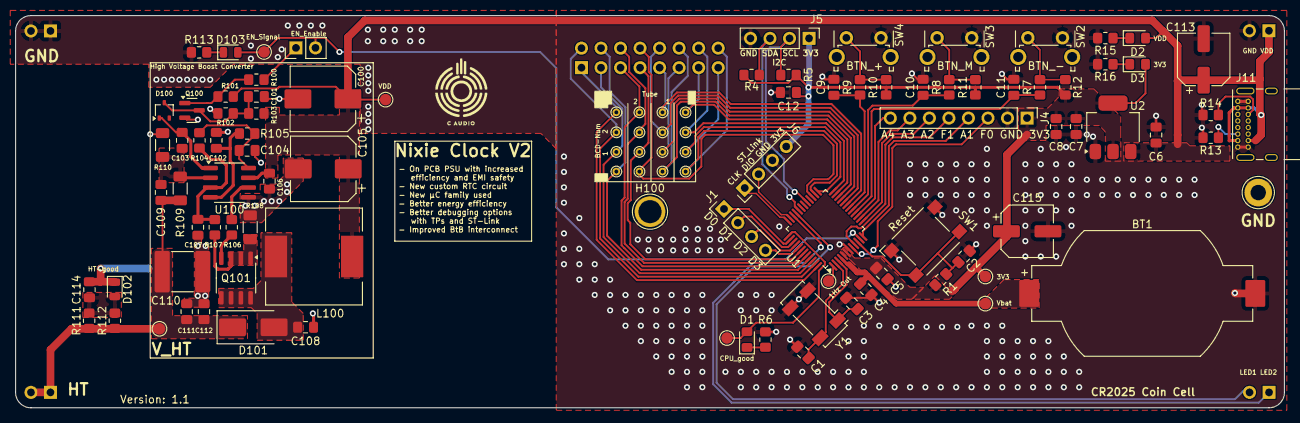
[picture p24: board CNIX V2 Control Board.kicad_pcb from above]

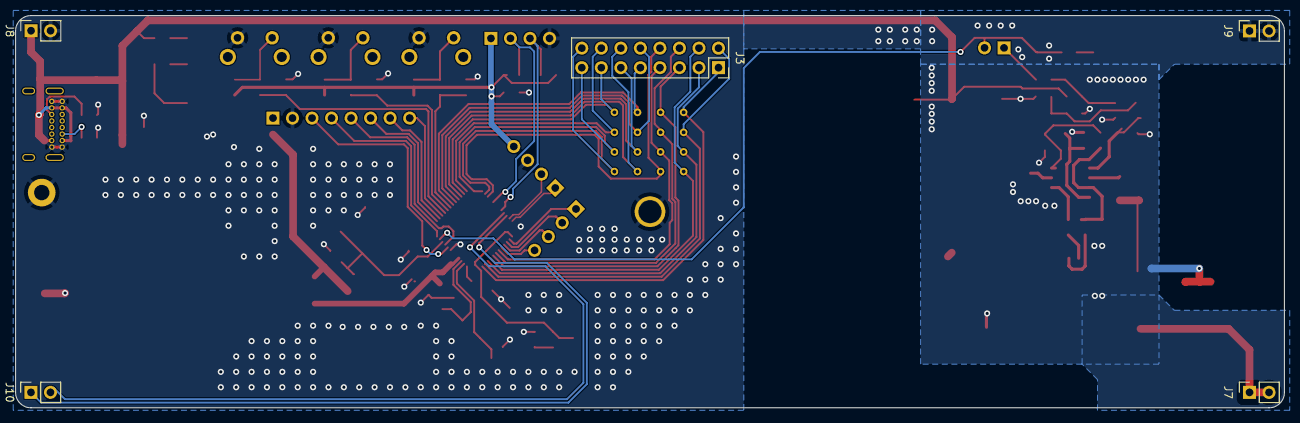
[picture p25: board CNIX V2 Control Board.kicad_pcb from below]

Board: 2 copper layers, 165.0 x 51.0 mm, 111 parts (5 on the bottom side), 68 nets.

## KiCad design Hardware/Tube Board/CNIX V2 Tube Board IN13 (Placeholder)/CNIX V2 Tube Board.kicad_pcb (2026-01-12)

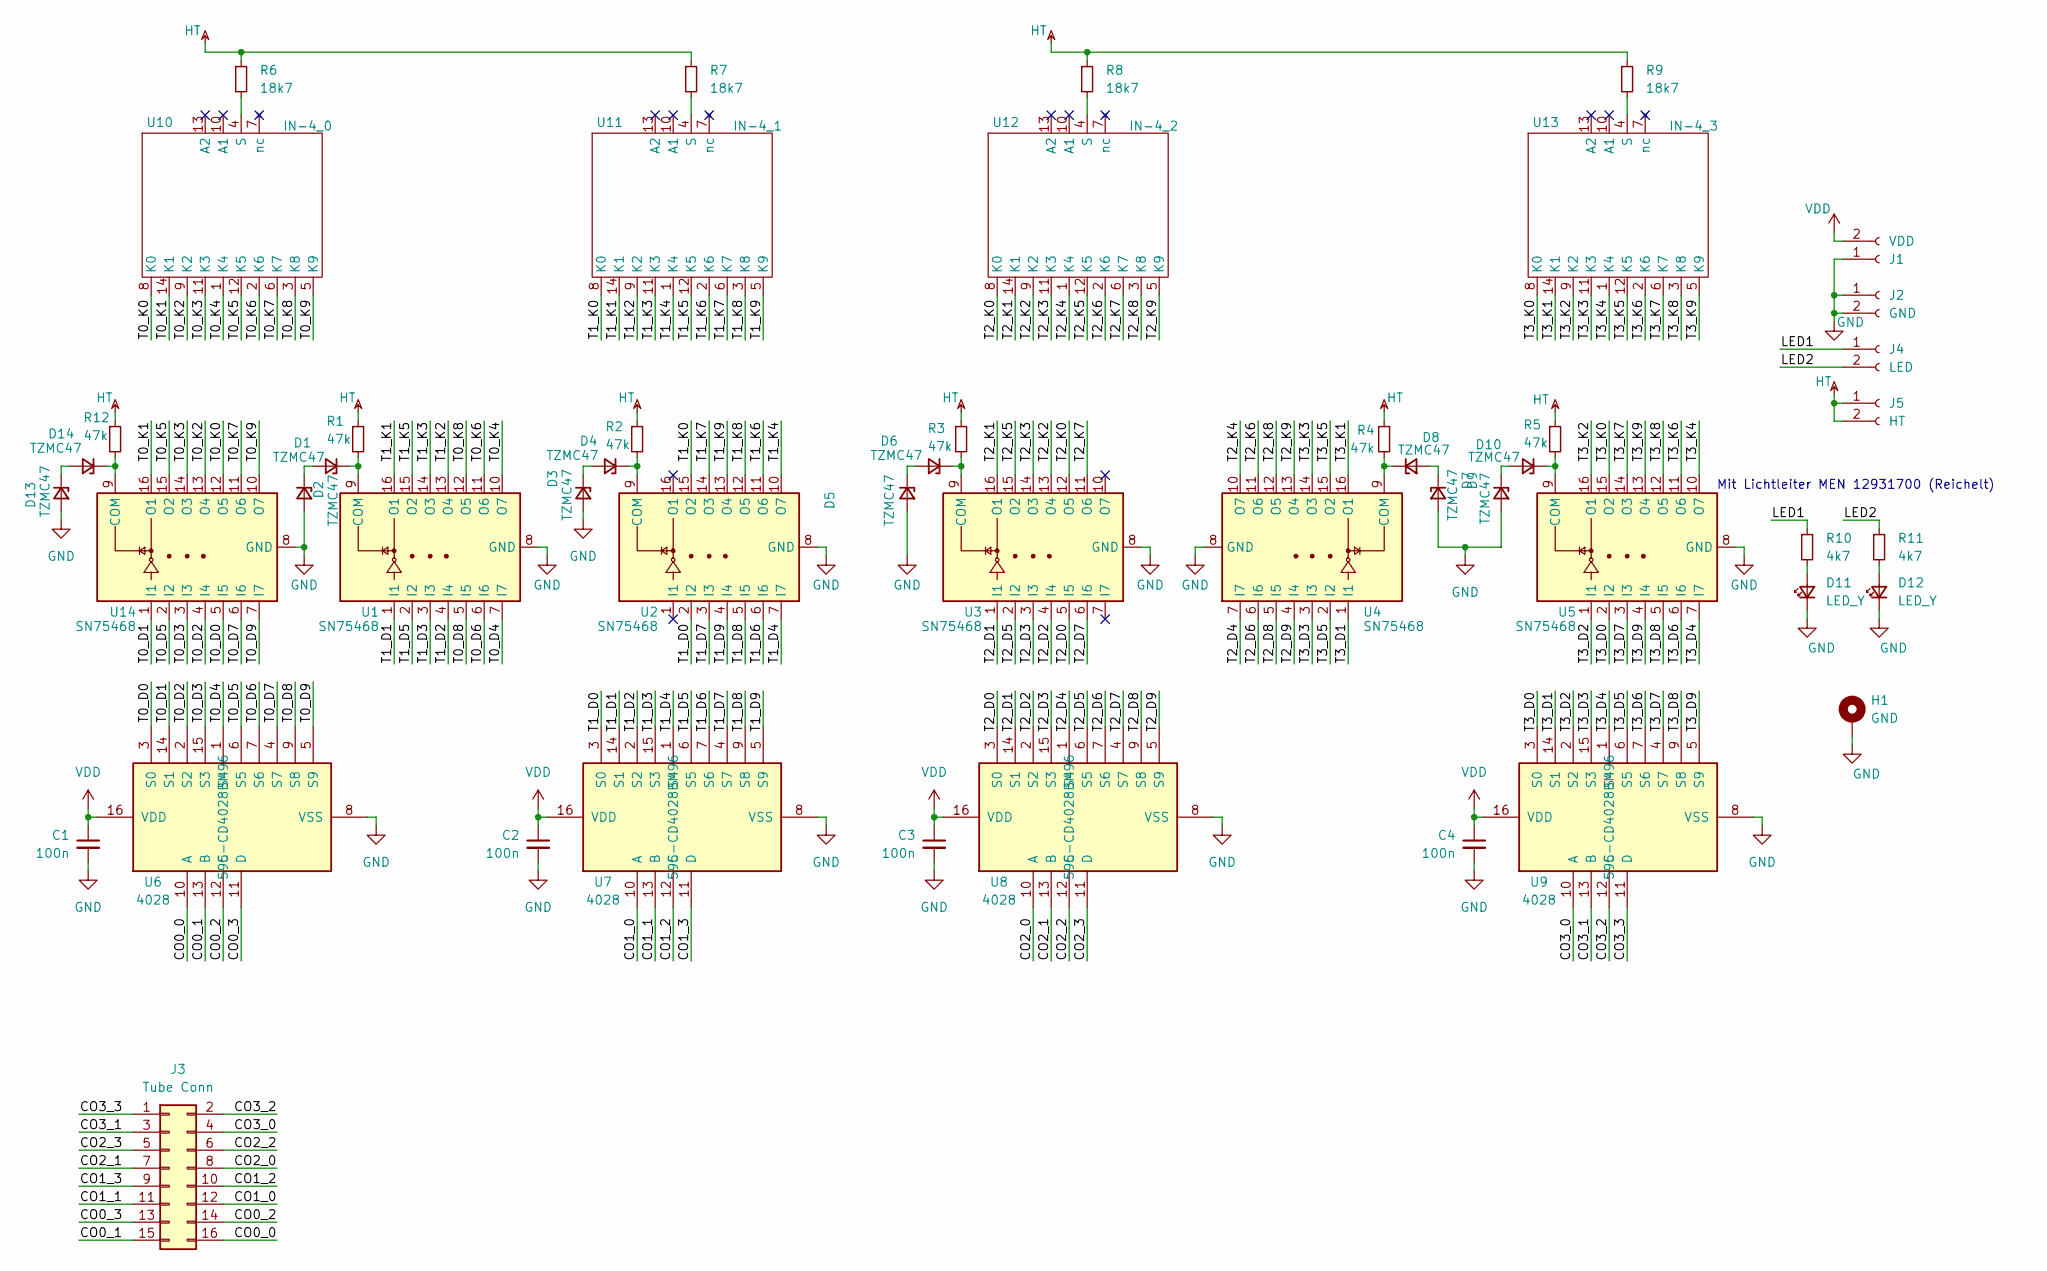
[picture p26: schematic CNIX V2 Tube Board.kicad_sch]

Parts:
C1, C2, C3, C4: 100n; C_0805_2012Metric_Pad1.18x1.45mm_HandSolder
D1, D2, D3, D4, D5, D6, D7, D8, D9, D10, D13, D14: TZMC47; D_MiniMELF; Mouser URL 78-TZMC47
D11, D12: LED_Y; LED_0805_2012Metric_Pad1.15x1.40mm_HandSolder
H1: GND; TestPoint_Plated_Hole_D3.0mm
J1: VDD; PinHeader_1x02_P2.54mm_Vertical
J2: GND; PinHeader_1x02_P2.54mm_Vertical
J3: Tube Conn; PinHeader_2x08_P2.54mm_Vertical
J4: LED; PinHeader_1x02_P2.54mm_Vertical
J5: HT; PinHeader_1x02_P2.54mm_Vertical
R1, R2, R3, R4, R5, R12: 47k; R_0805_2012Metric; Mouser Nr. 603-AC0805FR-1347KL
R6, R7, R8, R9: 18k7; R_1206_3216Metric_Pad1.30x1.75mm_HandSolder; Mouser Nr. 603-RC1206FR-0718K7L
R10, R11: 4k7; R_0805_2012Metric_Pad1.20x1.40mm_HandSolder; Mouser Nr. 603-RC0805FR-074K7P
U1, U2, U3, U4, U5, U14: SN75468; SOIC-16_3.9x9.9mm_P1.27mm; Mouser Nr. 595-SN75468DR
U6, U7, U8, U9: 4028; SOIC-16_3.9x9.9mm_P1.27mm; Mouser Nr. 595-CD4028BM96
U10: IN-4_0; IN-4
U11: IN-4_1; IN-4
U12: IN-4_2; IN-4
U13: IN-4_3; IN-4

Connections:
/CO0_0: J3.16, U6.10 (A)
/CO0_1: J3.15, U6.13 (B)
/CO0_2: J3.14, U6.12 (C)
/CO0_3: J3.13, U6.11 (D)
/CO1_0: J3.12, U7.10 (A)
/CO1_1: J3.11, U7.13 (B)
/CO1_2: J3.10, U7.12 (C)
/CO1_3: J3.9, U7.11 (D)
/CO2_0: J3.8, U8.10 (A)
/CO2_1: J3.7, U8.13 (B)
/CO2_2: J3.6, U8.12 (C)
/CO2_3: J3.5, U8.11 (D)
/CO3_0: J3.4, U9.10 (A)
/CO3_1: J3.3, U9.13 (B)
/CO3_2: J3.2, U9.12 (C)
/CO3_3: J3.1, U9.11 (D)
/LED1: J4.1, R10.1
/LED2: J4.2, R11.1
/T0_D0: U6.3 (S0), U14.5 (I5)
/T0_D1: U6.14 (S1), U14.1 (I1)
/T0_D2: U6.2 (S2), U14.4 (I4)
/T0_D3: U6.15 (S3), U14.3 (I3)
/T0_D4: U1.7 (I7), U6.1 (S4)
/T0_D5: U6.6 (S5), U14.2 (I2)
/T0_D6: U1.6 (I6), U6.7 (S6)
/T0_D7: U6.4 (S7), U14.6 (I6)
/T0_D8: U1.5 (I5), U6.9 (S8)
/T0_D9: U6.5 (S9), U14.7 (I7)
/T0_K0: U10.8 (K0), U14.12 (O5)
/T0_K1: U10.14 (K1), U14.16 (O1)
/T0_K2: U10.9 (K2), U14.13 (O4)
/T0_K3: U10.11 (K3), U14.14 (O3)
/T0_K4: U1.10 (O7), U10.1 (K4)
/T0_K5: U10.12 (K5), U14.15 (O2)
/T0_K6: U1.11 (O6), U10.2 (K6)
/T0_K7: U10.6 (K7), U14.11 (O6)
/T0_K8: U1.12 (O5), U10.3 (K8)
/T0_K9: U10.5 (K9), U14.10 (O7)
/T1_D0: U2.2 (I2), U7.3 (S0)
/T1_D1: U1.1 (I1), U7.14 (S1)
/T1_D2: U1.4 (I4), U7.2 (S2)
/T1_D3: U1.3 (I3), U7.15 (S3)
/T1_D4: U2.7 (I7), U7.1 (S4)
/T1_D5: U1.2 (I2), U7.6 (S5)
/T1_D6: U2.6 (I6), U7.7 (S6)
/T1_D7: U2.3 (I3), U7.4 (S7)
/T1_D8: U2.5 (I5), U7.9 (S8)
/T1_D9: U2.4 (I4), U7.5 (S9)
/T1_K0: U2.15 (O2), U11.8 (K0)
/T1_K1: U1.16 (O1), U11.14 (K1)
/T1_K2: U1.13 (O4), U11.9 (K2)
/T1_K3: U1.14 (O3), U11.11 (K3)
/T1_K4: U2.10 (O7), U11.1 (K4)
/T1_K5: U1.15 (O2), U11.12 (K5)
/T1_K6: U2.11 (O6), U11.2 (K6)
/T1_K7: U2.14 (O3), U11.6 (K7)
/T1_K8: U2.12 (O5), U11.3 (K8)
/T1_K9: U2.13 (O4), U11.5 (K9)
/T2_D0: U3.5 (I5), U8.3 (S0)
/T2_D1: U3.1 (I1), U8.14 (S1)
/T2_D2: U3.4 (I4), U8.2 (S2)
/T2_D3: U3.3 (I3), U8.15 (S3)
/T2_D4: U4.7 (I7), U8.1 (S4)
/T2_D5: U3.2 (I2), U8.6 (S5)
/T2_D6: U4.6 (I6), U8.7 (S6)
/T2_D7: U3.6 (I6), U8.4 (S7)
/T2_D8: U4.5 (I5), U8.9 (S8)
/T2_D9: U4.4 (I4), U8.5 (S9)
/T2_K0: U3.12 (O5), U12.8 (K0)
/T2_K1: U3.16 (O1), U12.14 (K1)
/T2_K2: U3.13 (O4), U12.9 (K2)
/T2_K3: U3.14 (O3), U12.11 (K3)
/T2_K4: U4.10 (O7), U12.1 (K4)
/T2_K5: U3.15 (O2), U12.12 (K5)
/T2_K6: U4.11 (O6), U12.2 (K6)
/T2_K7: U3.11 (O6), U12.6 (K7)
/T2_K8: U4.12 (O5), U12.3 (K8)
/T2_K9: U4.13 (O4), U12.5 (K9)
/T3_D0: U5.2 (I2), U9.3 (S0)
/T3_D1: U4.1 (I1), U9.14 (S1)
/T3_D2: U5.1 (I1), U9.2 (S2)
/T3_D3: U4.3 (I3), U9.15 (S3)
/T3_D4: U5.7 (I7), U9.1 (S4)
/T3_D5: U4.2 (I2), U9.6 (S5)
/T3_D6: U5.6 (I6), U9.7 (S6)
/T3_D7: U5.3 (I3), U9.4 (S7)
/T3_D8: U5.5 (I5), U9.9 (S8)
/T3_D9: U5.4 (I4), U9.5 (S9)
/T3_K0: U5.15 (O2), U13.8 (K0)
/T3_K1: U4.16 (O1), U13.14 (K1)
/T3_K2: U5.16 (O1), U13.9 (K2)
/T3_K3: U4.14 (O3), U13.11 (K3)
/T3_K4: U5.10 (O7), U13.1 (K4)
/T3_K5: U4.15 (O2), U13.12 (K5)
/T3_K6: U5.11 (O6), U13.2 (K6)
/T3_K7: U5.14 (O3), U13.6 (K7)
/T3_K8: U5.12 (O5), U13.3 (K8)
/T3_K9: U5.13 (O4), U13.5 (K9)
GND: C1.2, C2.2, C3.2, C4.2, D2.2 (A), D3.2 (A), D5.2 (A), D7.2 (A), D9.2 (A), D11.1 (K), D12.1 (K), D13.2 (A), H1.1, J1.1, J2.1, J2.2, U1.8 (GND), U2.8 (GND), U3.8 (GND), U4.8 (GND), U5.8 (GND), U6.8 (VSS), U7.8 (VSS), U8.8 (VSS), U9.8 (VSS), U14.8 (GND)
HT: J5.1, J5.2, R1.1, R2.1, R3.1, R4.1, R5.1, R6.1, R7.1, R8.1, R9.1, R12.1
unnamed: D1.2 (A), D2.1 (K)
unnamed: D1.1 (K), R1.2, U1.9 (COM)
unnamed: D3.1 (K), D4.2 (A)
unnamed: D4.1 (K), R2.2, U2.9 (COM)
unnamed: D5.1 (K), D6.2 (A)
unnamed: D6.1 (K), R3.2, U3.9 (COM)
unnamed: D7.1 (K), D8.2 (A)
unnamed: D8.1 (K), R4.2, U4.9 (COM)
unnamed: D9.1 (K), D10.2 (A)
unnamed: D10.1 (K), R5.2, U5.9 (COM)
unnamed: D11.2 (A), R10.2
unnamed: D12.2 (A), R11.2
unnamed: D13.1 (K), D14.2 (A)
unnamed: D14.1 (K), R12.2, U14.9 (COM)
unnamed: R6.2, U10.4 (S)
unnamed: R7.2, U11.4 (S)
unnamed: R8.2, U12.4 (S)
unnamed: R9.2, U13.4 (S)
VDD: C1.1, C2.1, C3.1, C4.1, J1.2, U6.16 (VDD), U7.16 (VDD), U8.16 (VDD), U9.16 (VDD)

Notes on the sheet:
Mit Lichtleiter MEN 12931700 (Reichelt)

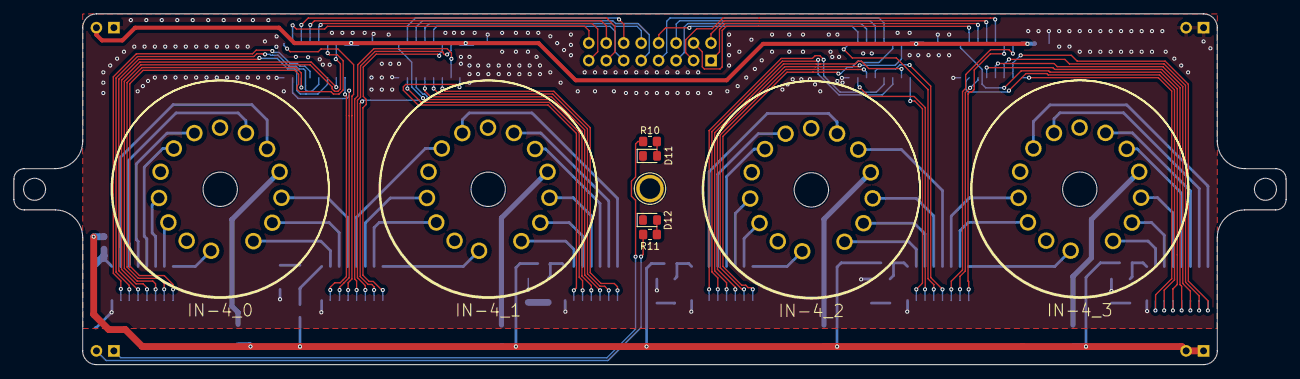
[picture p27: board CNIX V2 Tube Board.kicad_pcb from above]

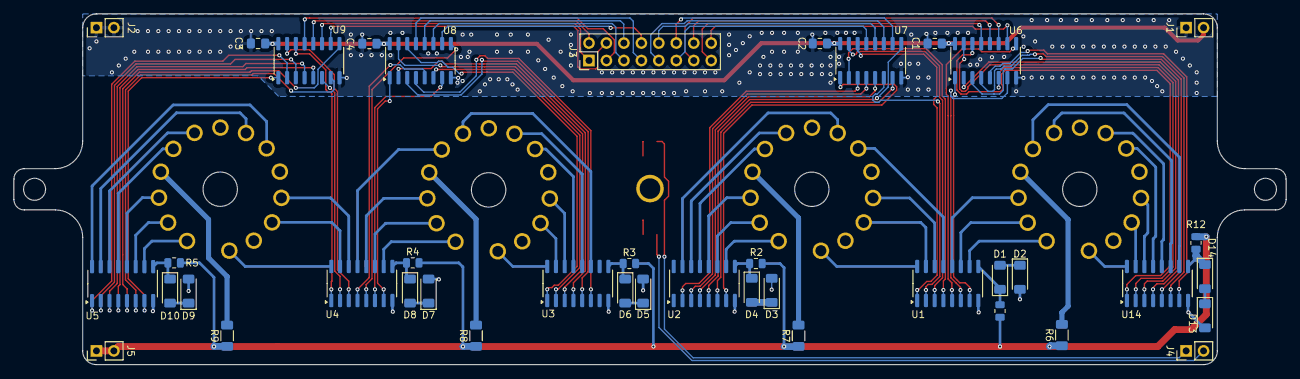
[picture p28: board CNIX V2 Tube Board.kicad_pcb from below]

Board: 2 copper layers, 185.0 x 51.0 mm, 50 parts (41 on the bottom side), 119 nets.

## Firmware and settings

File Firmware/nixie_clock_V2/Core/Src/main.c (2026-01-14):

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
/* Includes ------------------------------------------------------------------*/
#include "main.h"

/* USER CODE BEGIN Includes */
#include "cmsis_gcc.h"
#include "ssd1306_fonts.h"
#include "stm32g051xx.h"
#include "stm32g0xx_hal.h"
#include "stm32g0xx_hal_def.h"
#include "stm32g0xx_hal_gpio.h"
#include "stm32g0xx_hal_rtc.h"
#include "stm32g0xx_hal_rtc_ex.h"

#include <stdint.h>
#include "stdio.h"
#include "ssd1306.h"
#include "output_tube.h"
#include "menu.h"
#include "stm32g0xx_hal_tim.h"
#include "dht22.h"
/* USER CODE END Includes */

/* USER CODE BEGIN PTD */
/**
 * DataDigital struct to hold digital values of the time from RTC
 */
struct time_date_DataDigital {
  uint8_t hours, minutes, seconds;

  uint8_t day, weekday, month, year;
} TD_data;

/* USER CODE END PTD */

/* USER CODE BEGIN PM */

#define DISPLAY_TIME_DATE_X_OFFSET 42
#define DISPLAY_TIME_Y_OFFSET       0
#define DISPLAY_DATE_Y_OFFSET      11
#define DISPLAY_MISC_Y_OFFSET      22
#define DISPLAY_MISC_X_OFFSET     112

/**
 * These should only be used one time at the first programming of the mcu. When you do have to manually set the time, just 
 * put the right data here and change the RANDOM_SEED_OFFSET to something diffrent than the current value (16bit)
 */
#define RANDOM_SEED_UPDATE 0x2344

#define CURRENT_TIME_HOURS   13
#define CURRENT_TIME_MINUTES 13
#define CURRENT_TIME_SECONDS  0

#define CURRENT_DATE_YEAR    25
#define CURRENT_DATE_MONTH   12
#define CURRENT_DATE_DAY     16
#define CURRENT_DATE_WEEKDAY  2

//Interval in which the time updates. 1s for oled screen and second accuracy, 60 for nixie display
#define UPDATE_INTERVAL 60  

//Reset time for the display of the menu button on the oled
#define DISPLAY_MENU_RESET_TIME 750

//Timeouts for the menus. 10s for temp and hmd, 60s for everything else
#define DISPLAY_MENU_1_TIMEOUT 10000
#define DISPLAY_MENU_X_TIMEOUT 60000

#define set 1
#define true 1
#define isSet 1
#define isPressed 1

#define reset 0
#define false 0
#define isNotSet 0
#define isNotPressed 0

//--------------------------------------------------------- Menu stuff makros and variables

#define menu_size 8

/**
 * @brief: Main menu structure for the whole clock
 * @param 0 -> normal time display
 * @param 1 -> Temperature and humidity sensor (Timeout 5s)
 * @param 2 -> Start/stop Time (time setting like above, but for start AND stop time) (Maybe multiple ones for morning and evening times?) (Timeout 30s) (Override with long press till next shutoff?)
 * @param 3 -> Time set (GETS DISABLED WHEN DCF77 PLUGIN BOARD ARE USED) (1. hours tens; 2. hours ones; 3. minutes tens; 4. minutes ones) (Timeout 30s)
 */
uint8_t menu_pos = 0;
uint8_t menu_pos_old = 0;

uint16_t menu_time_set[4] = {1010,110,101,11};
/* USER CODE END PM */

I2C_HandleTypeDef hi2c1;

RTC_HandleTypeDef hrtc;

TIM_HandleTypeDef htim1;

/* USER CODE BEGIN PV */
volatile uint8_t tick_flag = isNotSet;
volatile uint8_t counter_seconds = 0;

/**
 * Value of the button being pressed.
 * 1: MINUS
 * 2: MENU
 * 3: PLUS
 */
volatile int8_t btn_flag_menu  = 0;
volatile int8_t btn_flag_plus  = 0;
volatile int8_t btn_flag_minus = 0;

//used for blinking the screen when in menu. Set to DISPLAY_BLINK_TIME
volatile uint8_t tick_blink = 0;
uint8_t tick_blink_flag = 0;

uint8_t btn_pressed_flag = isNotPressed;

//for when the sensor is being used
volatile uint8_t sensor_flag = 0;

uint8_t id_read = 0b0011;

#if DEBUG_DISPLAY
/**
 * Char arrays to use strings directly on oled, could be omitted on final device.
 */
char timeData[15];
char dateData[15];
char miscData[2];
#endif

uint8_t check_if_addon();

HAL_StatusTypeDef setTime(uint8_t hour, uint8_t minute, uint8_t second);
HAL_StatusTypeDef setDate(uint8_t year, uint8_t month, uint8_t weekday, uint8_t date);
HAL_StatusTypeDef getTimeDate(char* time, char* date, struct time_date_DataDigital* dTime);

void set_tube_numbers(struct time_date_DataDigital* _time_date_data);
uint16_t combine_4bit_numbers(uint8_t num0, uint8_t num1, uint8_t num2, uint8_t num3);
void output_to_tubes(uint16_t _data);

void output_front_led(uint8_t led0, uint8_t led1);
void output_blink_front_leds(uint8_t _mode);

void menu1();
void menu_startStop();
void menu_timeSet();
void menu_timeout(uint8_t _menu_pos);

/**
 * main counter for getTick function
 */
uint32_t start_ms_counter = 0;
uint32_t start_ms_counter_blink = 0;
uint32_t start_ms_counter_menuTimeout = 0;
uint8_t  error_count = 0;

/* USER CODE END PV */

void SystemClock_Config(void);
static void MX_GPIO_Init(void);
static void MX_I2C1_Init(void);
static void MX_RTC_Init(void);
static void MX_TIM1_Init(void);
/* USER CODE BEGIN PFP */

#if DEBUG_DISPLAY
void ssd1306_writeTime(char* time);
void ssd1306_writeDate(char* date);
void ssd1306_writeTimeDate(char* time, char* date);
void ssd1306_writeMisc(char* _data);
#endif

/* USER CODE END PFP */

/**
  * @brief  The application entry point.
  * @retval int
  */
int main(void)
{

  /* MCU Configuration--------------------------------------------------------*/

  /* Reset of all peripherals, Initializes the Flash interface and the Systick. */
  HAL_Init();

  /* Configure the system clock */
  SystemClock_Config();

  /* Initialize all configured peripherals */
  MX_GPIO_Init();
  MX_I2C1_Init();
  MX_RTC_Init();
  MX_TIM1_Init();
  /* USER CODE BEGIN 2 */

  HAL_TIM_Base_Start_IT(&htim1);

  //Initialize the RTC
  HAL_RTC_Init(&hrtc);

  /**
   * If the random number stored in the backup register is diffrent from the current value, its not updating the Time and Date. 
   * Seed, Time and Date are stored in makros 
   */
   if(HAL_RTCEx_BKUPRead(&hrtc, RTC_BKP_DR1) != RANDOM_SEED_UPDATE) {
    setTime(CURRENT_TIME_HOURS, CURRENT_TIME_MINUTES, CURRENT_TIME_SECONDS);
    setDate(CURRENT_DATE_YEAR, CURRENT_DATE_MONTH, CURRENT_DATE_WEEKDAY, CURRENT_DATE_DAY);
  }
  
  __disable_irq();
  //Try 10 times or till a HAL_OK is retrieved to get the time from RTC
  if(getTimeDate(timeData, dateData, &TD_data) != HAL_OK) {
    HAL_StatusTypeDef _Status = HAL_ERROR;
    uint8_t tries = 0;
    while((_Status == HAL_ERROR) || (tries <= 10)) {
      _Status = getTimeDate(timeData, dateData, &TD_data);
      tries++;
    }
  }
  __enable_irq();

  //Set the Front LEDs On
  output_front_led(1, 1);

  //Output current time to tubes
  set_tube_numbers(&TD_data);
  
  #if DEBUG_DISPLAY
  /**
   * Constructor for the basic oled menu with predeceeding welcome message
   * // TODO LATER create a module check and modules (e.g. WIFI time sync, smart home features, etc.)
   */
  
  ssd1306_Init();
  ssd1306_SetCursor(10, 10);
  ssd1306_WriteString("Nixie Clock V2", Font_7x10, White);
  ssd1306_UpdateScreen();
  HAL_Delay(500);
  ssd1306_Fill(Black);
  ssd1306_SetCursor(0, 0);
  ssd1306_WriteString("Time: ", Font_7x10, White);
  ssd1306_writeTime(timeData);
  ssd1306_SetCursor(0, 11);
  ssd1306_WriteString("Date: ", Font_7x10, White);
  ssd1306_writeDate(dateData);
  ssd1306_SetCursor(0, 22);
  ssd1306_WriteString("Menu Position: ", Font_7x10, White);
  miscData[0] = '0';
  ssd1306_writeMisc(miscData);
  ssd1306_UpdateScreen();
  #endif

  //check for installed submodules
  id_read = check_if_addon();

  /* USER CODE END 2 */

  /* Infinite loop */
  /* USER CODE BEGIN WHILE */
  while (1)
  {
    if(tick_flag == isSet) { //flag set by interrupt by RTC on 1Hz

      getTimeDate(timeData, dateData, &TD_data);      //Get tiome from RTC registers

      #if DEBUG_DISPLAY
      ssd1306_writeTimeDate(timeData, dateData);
      #endif

      //Update Nixies, they dont have seconds!
      if(TD_data.seconds == 0) {
        set_tube_numbers(&TD_data);
      }

      if(menu_pos == 1) {
        counter_seconds++;
        if(counter_seconds >=4) {
          sensor_flag = 1;
          counter_seconds = 0;
        }
      }

      tick_flag = reset; //reset update flag
    }

    /**
     * Reset button number after some time (defined in DISPLAY_MENU_RESET_TIME)
     */
    if(btn_pressed_flag && ((HAL_GetTick()-start_ms_counter) > DISPLAY_MENU_RESET_TIME)) {

      miscData[0] = '0';
      ssd1306_writeMisc(miscData);
      btn_pressed_flag = isNotPressed;
    }

    //only start one time per menu change
    if(menu_pos != menu_pos_old)  { 
      start_ms_counter_menuTimeout = HAL_GetTick();
      menu_pos_old = menu_pos;
    }
    
    //If menu_pos is other than normal time setting (=0), go into this MAIN MENU STRUCTURE
    if(menu_pos != 0) {

      switch(menu_pos) {
        case 1: //Display Temp and Hmd on nixie tubes. Left Temp, right hmd. TIMEOUT = 10s
          if(id_read != 0x0) {
            menu_pos++;
            break;  //Skips this menu when no DCF77 addon board is connected
          }
          
          menu_timeout(1);
          menu1();
          output_blink_front_leds(0);

          break; 

        case 2: case 3: //Set start time of the clock. Can be set multiple times for a morning and evening routine TIMEOUT = 60s         
          menu_timeout(2);
          menu_startStop();
          output_blink_front_leds(2);
          
          break;  

        case 4: case 5: //Set stop time of the clock.
          menu_timeout(2);
          menu_startStop();
          output_blink_front_leds(3);

          break;

        case 6: case 7: //Set the time manually. must be disabled when module '00' is used (DCF77) TIMEOUT = 60s   
          menu_timeout(3);
          menu_timeSet();
          output_blink_front_leds(1);
          break;

        default: break;
      }

      btn_flag_menu =  reset;
      btn_flag_minus = reset;
      btn_flag_plus =  reset;   
    } else if(menu_pos == 0) output_front_led(1, 1);
    
    #ifdef DEBUG
    sprintf(miscData, "%01d", menu_pos);
    ssd1306_writeMisc(miscData);
    #endif
    
    /**
     * Debug function for development of the buttons
     */
    /*
    if((btn_flag_plus == isPressed) || (btn_flag_menu == isPressed) || (btn_flag_minus == isPressed)) {

      if(btn_flag_menu) {
        miscData[0] = 'M';
        ssd1306_writeMisc(miscData);
      }
      if(btn_flag_plus) {
        miscData[0] = '+';
        ssd1306_writeMisc(miscData);
      }
      if(btn_flag_minus) {
        miscData[0] = '-';
        ssd1306_writeMisc(miscData);
      }
      */
      
      
      /*Turns on the HT PSU
      switch (btn_flag) {
        case 2:

          HAL_GPIO_TogglePin(ht_EN_GPIO_Port, ht_EN_Pin);
          break;

        default:
          break;
      } */

      //start_ms_counter = HAL_GetTick();
      //btn_pressed_flag = isPressed;
      /*
      btn_flag_menu =  reset;
      btn_flag_minus = reset;
      btn_flag_plus =  reset;
    }
    */
    /* USER CODE END WHILE */

    /* USER CODE BEGIN 3 */
  }
  /* USER CODE END 3 */
}

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
/* USER CODE BEGIN 4 */

uint8_t check_if_addon() {
  //Checks both id_bit0 and id_bit1 and combines them.
  return (((GPIOD->IDR & GPIO_IDR_ID3) << 1) | (GPIOD->IDR & GPIO_IDR_ID2));
}

/**
 * Sets the Time of the RTC. IMPORTANT: When regenerating the code through CubeMX comment out the time setting in the predefined function.
 * This is to only update the time when needed and not every time you program the MCU. The check is made through the Backup register DR1, to which a 
 * random number is written. Only update the time when this number is not the same on startup!
 */
HAL_StatusTypeDef setTime(uint8_t hour, uint8_t minute, uint8_t second) {
  RTC_TimeTypeDef sTime = {0};
  sTime.Hours = hour;
  sTime.Minutes = minute;
  sTime.Seconds = second;
  sTime.SubSeconds = 0x0;

  if (HAL_RTC_SetTime(&hrtc, &sTime, RTC_FORMAT_BIN) != HAL_OK)
  {
    return HAL_ERROR;
  }
  HAL_RTC_DST_Sub1Hour(&hrtc);  // TODO Daylight Saving Time,check for last sunday of march and last sunday in october to set opr unset DST. 
  return HAL_OK;
}

/**
 * Sets the Date of the RTC. IMPORTANT: When regenerating the code through CubeMX comment out the date setting in the predefined function.
 * This is to only update the date when needed and not every time you program the MCU. The check is made through the Backup register DR1, to which a 
 * random number is written. Only update the Date when this number is not the same on startup!
 */
HAL_StatusTypeDef setDate(uint8_t year, uint8_t month, uint8_t weekday, uint8_t date) { //weekday->Monday = 1, date->which day in month (0-31) 
  RTC_DateTypeDef sDate = {0};
  sDate.WeekDay = weekday;
  sDate.Month = month;
  sDate.Date = date;
  sDate.Year = year;

  if (HAL_RTC_SetDate(&hrtc, &sDate, RTC_FORMAT_BIN) != HAL_OK)
  {
    return HAL_ERROR;
  }

  HAL_RTCEx_BKUPWrite(&hrtc, RTC_BKP_DR1, RANDOM_SEED_UPDATE);
  
  return HAL_OK;
}

/**
 * Function to get time and date from RTC module. IMPORTANT: Always get time and then date TOGETHER! otherwize the druids of the forest will hunt you
 * Creates strings in predefined vhar arrays to directly print to an oled.
 * TODO: put time and date in an integer struct to push to the nixies 
 */
HAL_StatusTypeDef getTimeDate(char* time, char* date, struct time_date_DataDigital* dTime) {
  RTC_DateTypeDef gDate;
  RTC_TimeTypeDef gTime;
  uint8_t _error_count = 0;

  //Get current time
  if(HAL_RTC_GetTime(&hrtc, &gTime, RTC_FORMAT_BIN) != HAL_OK) _error_count++;

  //Get current date
  if(HAL_RTC_GetDate(&hrtc, &gDate, RTC_FORMAT_BIN) != HAL_OK) _error_count++;

  dTime->hours = gTime.Hours;
  dTime->minutes = gTime.Minutes;
  dTime->seconds = gTime.Seconds;

  dTime->day = gDate.Date;
  dTime->weekday = gDate.WeekDay;
  dTime->month = gDate.Month;
  dTime->year = gDate.Year;

  #if DEBUG_DISPLAY
  /* Display time Format: hh:mm:ss */
  sprintf(time,"%02d:%02d:%02d",gTime.Hours, gTime.Minutes, gTime.Seconds);

  /* Display date Format: dd-mm-yyyy */
  sprintf(date,"%02d-%02d-%2d",gDate.Date, gDate.Month, 2000 + gDate.Year);
  #endif

  if(_error_count != 0) return HAL_ERROR;
  return HAL_OK;
}

/**
 * Combined oled writing function
 */
void ssd1306_writeTimeDate(char* time, char* date) {
  ssd1306_SetCursor(DISPLAY_TIME_DATE_X_OFFSET, DISPLAY_TIME_Y_OFFSET);
  ssd1306_WriteString(time, Font_7x10, White);
  ssd1306_UpdateScreen();

  ssd1306_SetCursor(DISPLAY_TIME_DATE_X_OFFSET, DISPLAY_DATE_Y_OFFSET);
  ssd1306_WriteString(date, Font_7x10, White);
  ssd1306_UpdateScreen();
}

/**
 * Simplified function to display the date on an oled screen.
 * Cursor offsets are stored in makros 
 */
void ssd1306_writeTime(char* time) {
  ssd1306_SetCursor(DISPLAY_TIME_DATE_X_OFFSET, DISPLAY_TIME_Y_OFFSET);
  ssd1306_WriteString(time, Font_7x10, White);
  ssd1306_UpdateScreen();
}

/**
 * Simplified function to display the time on an oled screen.
 * Cursor offsets are stored in makros 
 */
void ssd1306_writeDate(char* date) {
  ssd1306_SetCursor(DISPLAY_TIME_DATE_X_OFFSET, DISPLAY_DATE_Y_OFFSET);
  ssd1306_WriteString(date, Font_7x10, White);
  ssd1306_UpdateScreen();
}

void ssd1306_writeMisc(char* _data) {
  ssd1306_SetCursor(DISPLAY_MISC_X_OFFSET, DISPLAY_MISC_Y_OFFSET);
  ssd1306_WriteString(_data, Font_7x10, White);
  ssd1306_UpdateScreen();
}

/** Function for changing the tubes to the corresponding time values
 */
void set_tube_numbers(struct time_date_DataDigital* _time_date_data) {

  //Start by extracting the single numbers out of the time struct to fuse them to a 16-Bit number later

  //Hours
  //calculate the tens
  uint8_t hours_tens = _time_date_data->hours / 10;
  //calculate the ones
  uint8_t hours_ones = _time_date_data->hours % 10;

  //Minutes
  //calculate the tens
  uint8_t minutes_tens = _time_date_data->minutes / 10;
  //calculate the ones
  uint8_t minutes_ones = _time_date_data->minutes % 10;

  /*Works miracilously perfectly :) but useless unless the PCB changes to accomondate for the correct pin order
  uint16_t _timeData_port = (hours_tens << 12) | (hours_ones << 8) | 
                            (minutes_tens << 4) | minutes_ones;
  */

  //Use variable in between the output and the bit sets for easy debugging. Speed does'nt matter
  //uint16_t _timeData_port_temp = combine_4bit_numbers(hours_tens, hours_ones, minutes_tens, minutes_ones);
  
  //Outputs 16bit data to the whole Port B of the micro. 
  output_to_tubes(combine_4bit_numbers(hours_tens, hours_ones, minutes_tens, minutes_ones));

  return;
}

/**
 * Sorts the bits to the correct spot for the output register TODO: Update PCB next time to have a nicer output register format not needing this shit -_-
 */
uint16_t combine_4bit_numbers(uint8_t num0, uint8_t num1, uint8_t num2, uint8_t num3) {

  uint16_t result = 0;

  // Bit 0: bit 3 von num1
  result |= ((num1 >> 3) & 0x1) << 0;
  // Bit 1: bit 2 von num1
  result |= ((num1 >> 2) & 0x1) << 1;
  // Bit 2: bit 1 von num1
  result |= ((num1 >> 1) & 0x1) << 2;
  // Bit 3: bit 1 von num2
  result |= ((num2 >> 1) & 0x1) << 3;
  // Bit 4: bit 2 von num2
  result |= ((num2 >> 2) & 0x1) << 4;
  // Bit 5: bit 3 von num2
  result |= ((num2 >> 3) & 0x1) << 5;
  // Bit 6: bit 0 von num3
  result |= ((num3 >> 0) & 0x1) << 6;
  // Bit 7: bit 1 von num3
  result |= ((num3 >> 1) & 0x1) << 7;
  // Bit 8: bit 2 von num3
  result |= ((num3 >> 2) & 0x1) << 8;
  // Bit 9: bit 3 von num3
  result |= ((num3 >> 3) & 0x1) << 9;
  // Bit 10: bit 0 von num1
  result |= ((num1 >> 0) & 0x1) << 10;
  // Bit 11: bit 3 von num0
  result |= ((num0 >> 3) & 0x1) << 11;
  // Bit 12: bit 2 von num0
  result |= ((num0 >> 2) & 0x1) << 12;
  // Bit 13: bit 1 von num0
  result |= ((num0 >> 1) & 0x1) << 13;
  // Bit 14: bit 0 von num0
  result |= ((num0 >> 0) & 0x1) << 14;
  // Bit 15: bit 0 von num2
  result |= ((num2 >> 0) & 0x1) << 15;

  return result;

}

void output_to_tubes(uint16_t _data) {
  //Output on the whole PORTB via the ODR (Output Data Register)
  GPIOB->ODR = _data;
}

void menu1() {
  if(sensor_flag) {
    uint8_t tempData_tens;
    uint8_t tempData_ones;
    uint8_t hmdData_tens;
    uint8_t hmdData_ones;
    
    DHT22_ReadData(&tempData_tens, &tempData_ones, &hmdData_tens, &hmdData_ones);
    output_to_tubes(combine_4bit_numbers(tempData_tens, tempData_ones, hmdData_tens, hmdData_ones));

    sensor_flag = 0;
  }
}

void menu_startStop() {
  
}

void menu_timeSet() {  
  
}

void menu_timeout(uint8_t _menu_pos) {

  if((btn_flag_plus == isPressed) || (btn_flag_menu == isPressed) || (btn_flag_minus == isPressed)) {
    start_ms_counter_menuTimeout = HAL_GetTick();
  }

  if(_menu_pos != 1) {

    //When timeout happens, get back to menu 0;
    if((HAL_GetTick()-start_ms_counter_menuTimeout) > DISPLAY_MENU_X_TIMEOUT) {
      menu_pos = 0;
      //start_ms_counter_menuTimeout = 0;
    }

  } else if (menu_pos == 1) {

    //When timeout happens, get back to menu 0;
    if((HAL_GetTick()-start_ms_counter_menuTimeout) > DISPLAY_MENU_1_TIMEOUT) {
      menu_pos = 0;
      //start_ms_counter_menuTimeout = 0;
    }

  }
}

/**
 * @brief: Function to blink the front leds.
 * @param mode: 0-> no blinking, 1-> both, 2-> top, 3-> bot
 */
void output_blink_front_leds(uint8_t _mode) {
  switch(_mode) {
    case 0: 
      output_front_led(1, 1);
      break;

    case 1: 
      output_front_led(tick_blink, tick_blink);
      break;

    case 2:
      output_front_led(tick_blink, 1);
      break;

    case 3:
      output_front_led(1, tick_blink);
      break;
  }
}

/**
 * @brief: Function to manipulate the front leds.
 * @param led0: top led
 * @param led1: bottom led
 * @param led_status: 0->off; 1->on
 */
void output_front_led(uint8_t led0, uint8_t led1) {

  if(led0)  GPIOA->BSRR = GPIO_BSRR_BS11;
  if(!led0) GPIOA->BSRR = GPIO_BSRR_BR11;

  if(led1)  GPIOA->BSRR = GPIO_BSRR_BS12;
  if(!led1) GPIOA->BSRR = GPIO_BSRR_BR12;
}

void HAL_TIM_PeriodElapsedCallback(TIM_HandleTypeDef *htim) {
  tick_blink = !tick_blink;
}

//Interrupt for triggering an update event every second
void HAL_RTCEx_WakeUpTimerEventCallback(RTC_HandleTypeDef *hrtc) {
  tick_flag = set;

  //counter_seconds++;
}


/**
 * Interrupt Handler for the buttons
 */
void HAL_GPIO_EXTI_Falling_Callback(uint16_t GPIO_Pin) {
  switch(GPIO_Pin) {
    case btn_plus_Pin:
      btn_flag_plus = 1;
      break;
    
    case btn_minus_Pin:
      btn_flag_minus = 1;
      break;

    case btn_menu_Pin:
      btn_flag_menu = 1;

      //Cycle through the menu positions through all menus (4 menus -> 0,1,2,3 -> so menu_size-1)
      if(menu_pos < menu_size-1) menu_pos++;
      else menu_pos = 0;
      
      if(menu_pos == 1) sensor_flag = 1;

      break;

    default:
      break;
  }
}

/* USER CODE END 4 */
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


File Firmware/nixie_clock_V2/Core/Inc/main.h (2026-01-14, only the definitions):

#define ht_EN_Pin GPIO_PIN_0
#define ht_EN_GPIO_Port GPIOA
#define dht22_pin_Pin GPIO_PIN_1
#define dht22_pin_GPIO_Port GPIOA
#define btn_minus_Pin GPIO_PIN_5
#define btn_minus_GPIO_Port GPIOA
#define btn_minus_EXTI_IRQn EXTI4_15_IRQn
#define btn_menu_Pin GPIO_PIN_6
#define btn_menu_GPIO_Port GPIOA
#define btn_menu_EXTI_IRQn EXTI4_15_IRQn
#define btn_plus_Pin GPIO_PIN_7
#define btn_plus_GPIO_Port GPIOA
#define btn_plus_EXTI_IRQn EXTI4_15_IRQn
#define co1_3_Pin GPIO_PIN_0
#define co1_3_GPIO_Port GPIOB
#define co1_2_Pin GPIO_PIN_1
#define co1_2_GPIO_Port GPIOB
#define co1_1_Pin GPIO_PIN_2
#define co1_1_GPIO_Port GPIOB
#define co1_0_Pin GPIO_PIN_10
#define co1_0_GPIO_Port GPIOB
#define co0_3_Pin GPIO_PIN_11
#define co0_3_GPIO_Port GPIOB
#define co0_2_Pin GPIO_PIN_12
#define co0_2_GPIO_Port GPIOB
#define co0_1_Pin GPIO_PIN_13
#define co0_1_GPIO_Port GPIOB
#define co0_0_Pin GPIO_PIN_14
#define co0_0_GPIO_Port GPIOB
#define co2_0_Pin GPIO_PIN_15
#define co2_0_GPIO_Port GPIOB
#define led_sig_bot_Pin GPIO_PIN_11
#define led_sig_bot_GPIO_Port GPIOA
#define led_sig_top_Pin GPIO_PIN_12
#define led_sig_top_GPIO_Port GPIOA
#define pwr_led_Pin GPIO_PIN_15
#define pwr_led_GPIO_Port GPIOA
#define id_bit0_Pin GPIO_PIN_2
#define id_bit0_GPIO_Port GPIOD
#define id_bit1_Pin GPIO_PIN_3
#define id_bit1_GPIO_Port GPIOD
#define co2_1_Pin GPIO_PIN_3
#define co2_1_GPIO_Port GPIOB
#define co2_2_Pin GPIO_PIN_4
#define co2_2_GPIO_Port GPIOB
#define co2_3_Pin GPIO_PIN_5
#define co2_3_GPIO_Port GPIOB
#define co3_0_Pin GPIO_PIN_6
#define co3_0_GPIO_Port GPIOB
#define co3_1_Pin GPIO_PIN_7
#define co3_1_GPIO_Port GPIOB
#define co3_2_Pin GPIO_PIN_8
#define co3_2_GPIO_Port GPIOB
#define co3_3_Pin GPIO_PIN_9
#define co3_3_GPIO_Port GPIOB
#define DEBUG_DISPLAY 1

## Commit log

2025-03-12 added bom and mouser nr
    [CNIX V2 Control Board.kicad_sch, psu.kicad_sch]
2025-03-25 added combined 3d model
    [CNIX V2 Control Board_BOM.csv, CNIX V2 Tube Board.kicad_sch, CNIX V2 Tube Board_BOM.csv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]
2025-04-02 added interactive BOM
2025-04-04 Added TODOs and changed cap values for the LSE
    [CNIX V2 Control Board.kicad_sch]
2026-01-09 pre tube board fix
    [main.c]
2026-01-09 finished wiring fix for the tube board
    [CNIX V2 Tube Board.kicad_pcb, CNIX V2 Tube Board.kicad_sch]
2026-01-12 finished tube PCB IN4 Version
    [CNIX V2 Tube Board.kicad_pcb]
2026-01-12 finished production files
    [CNIX V2 Tube Board-B_Cu.gbr, CNIX V2 Tube Board-B_Mask.gbr, CNIX V2 Tube Board-B_Paste.gbr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]
2026-01-12 added gitignore
    [CNIX V2 Tube Board.kicad_pcb, CNIX V2 Tube Board.kicad_sch, CNIX V2 Tube Board.step]
2026-01-13 control board version 2.1.1 bump and added changelog
    [CNIX V2 Control Board.kicad_pcb, DCF77-Addon.kicad_pcb, DCF77-Addon.kicad_sch]
2026-01-13 Version bump 2.2.0 -> new regulator and id system
    [CNIX V2 Control Board.kicad_pcb, CNIX V2 Control Board.kicad_sch, DCF77-Addon.kicad_pcb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]
2026-01-13 firmware update: blink timer and interrupt implemented; cleaned up main
2026-01-14 updated firmware: implemented DHT22 sensor, addon board id check, menu structure, led blink display
    [CNIX V2 Control Board.kicad_pcb, CNIX V2 Control Board.kicad_sch, CNIX V2 Control Board.sync-conflict-20260113-205112-62RYLVW.kicad_sch]
2026-01-14 control board: added ht-psu enable jumper
    [CNIX V2 Control Board.kicad_pcb, CNIX V2 Control Board.kicad_sch, psu.kicad_sch]
2026-01-24 added silkscreen and updated gerbers
    [CNIX V2 Control Board.sync-conflict-20260116-221704-62RYLVW.kicad_pcb, CNIX V2 Control Board.sync-conflict-20260116-221708-62RYLVW.kicad_sch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]
2026-03-16 Finished design
    [CNIX V2 Tube Board.sync-conflict-20260124-174513-YTMFTGM.kicad_sch]
2026-03-16 finalized design
    [CNIX V2 Tube Board.kicad_pcb]
2026-03-16 finalized DCF77 board and updated 3D pictures
    [DCF77 Addon.FCStd, DCF77-Addon.kicad_pcb, DCF77-Addon.kicad_sch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]
2026-03-16 finalized V2 and cleaned up Silkscreen
    [CNIX V2 Control Board.kicad_pcb, CNIX V2 Control Board.kicad_sch, psu.kicad_sch]
2026-03-16 finalized README
    [CNIX V2 Control Board.sync-conflict-20260113-205112-62RYLVW.kicad_sch, CNIX V2 Control Board.sync-conflict-20260116-221704-62RYLVW.kicad_pcb, CNIX V2 Control B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]
2026-03-26 finalized addon board and produced fabrication outputs
    [DCF77-Addon-B_Cu.gbr, DCF77-Addon-B_Mask.gbr, DCF77-Addon-B_Paste.gbr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]

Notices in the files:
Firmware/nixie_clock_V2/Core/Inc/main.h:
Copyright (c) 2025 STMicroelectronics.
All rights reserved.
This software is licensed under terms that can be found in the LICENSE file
